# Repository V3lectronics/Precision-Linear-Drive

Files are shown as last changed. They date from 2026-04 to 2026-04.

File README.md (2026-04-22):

# Precision-Linear-Drive

**Technical drawings available, see [DRAWINGS.pdf](DRAWINGS.pdf)**

Highly precise linear drive with a planetary gearbox coupled to a simple gear and clutch mechanism. The rotational motion is transferred to a screw mechanism which outputs linear motion. The motion range is limited by limit switches. The optical encoder allows for precise position feedback.





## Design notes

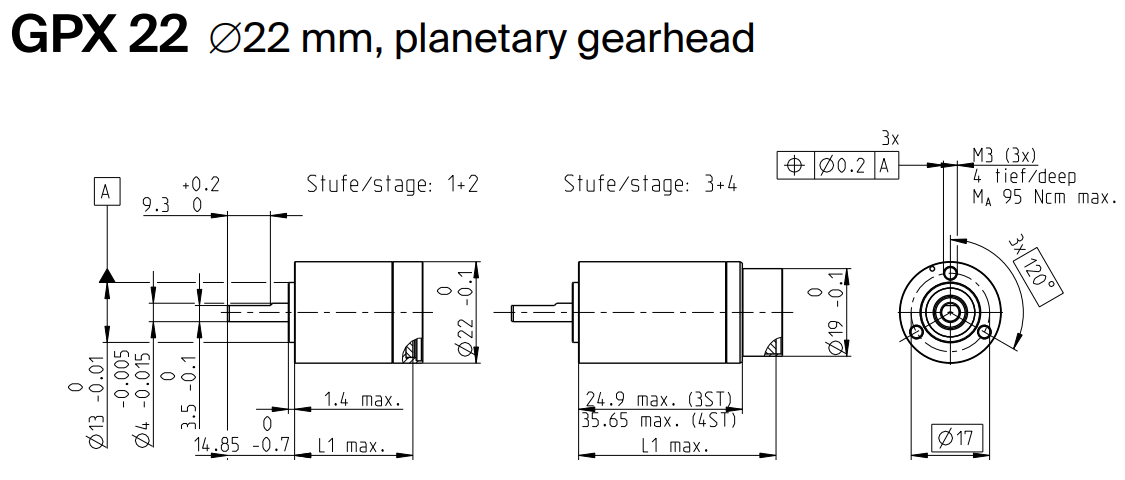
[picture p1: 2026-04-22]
motor-and-planetary-gear-info/Gear (1).PNG

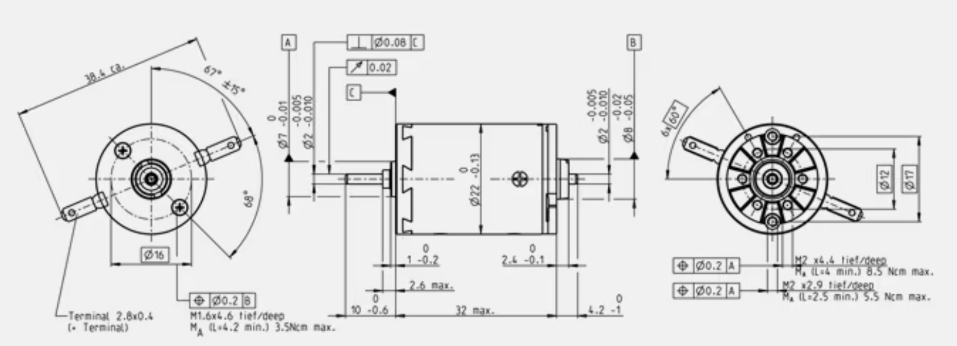
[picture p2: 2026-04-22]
motor-and-planetary-gear-info/Motor (1).PNG

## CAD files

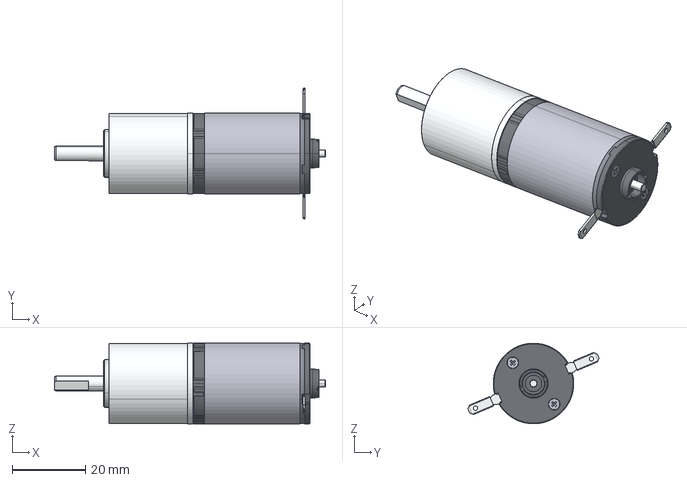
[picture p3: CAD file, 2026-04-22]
parts/motor-and-drive (1).stp
74.0 x 35.8 x 22.0 mm

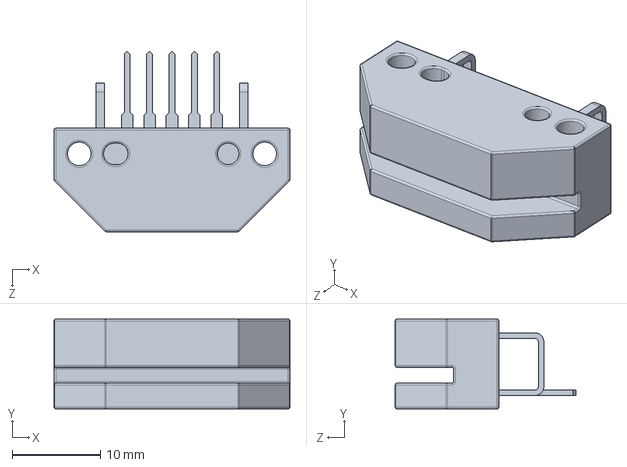
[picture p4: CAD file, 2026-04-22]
parts/HEDS9100 (1).sldprt
26.7 x 10.2 x 20.4 mm

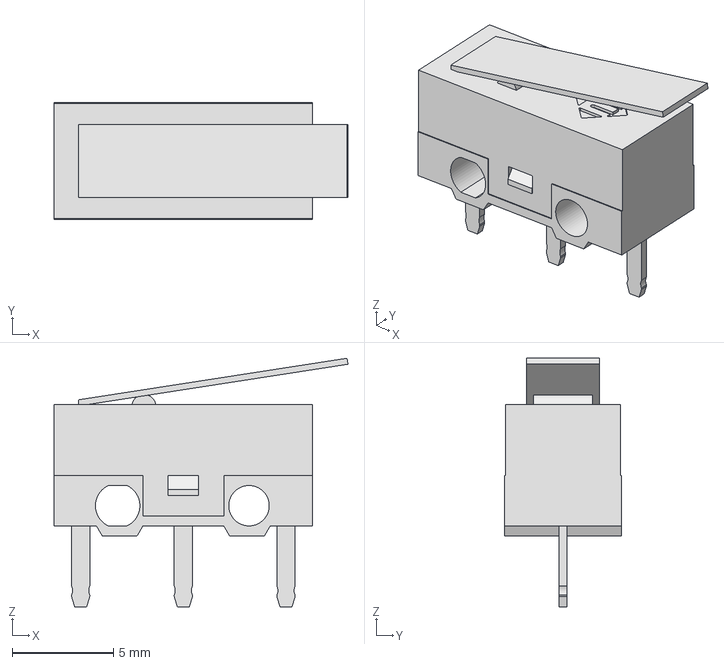
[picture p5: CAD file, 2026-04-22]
parts/SS0750301F040P1A (1).stp
14.5 x 5.80 x 12.3 mm

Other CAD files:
parts/rysunki (1)/tuleja łożyska-1.dwg
parts/rysunki (1)/nakrętka.dwg
parts/rysunki (1)/RYS złożeniowy (1).dwg
parts/rysunki (1)/płyta silnika.dwg
parts/rysunki (1)/słupek.dwg
parts/rysunki (1)/zespół płyty.dwg
parts/rysunki (1)/OldVersions (1)/RYS złożeniowy.0215.dwg
parts/rysunki (1)/OldVersions (1)/płyta silnika.0081.dwg
parts/rysunki (1)/OldVersions (1)/tuleja łożyska-1.0076.dwg
parts/rysunki (1)/OldVersions (1)/nakrętka.0101.dwg
parts/rysunki (1)/OldVersions (1)/zespół płyty.0015.dwg
parts/rysunki (1)/OldVersions (1)/słupek.0063.dwg
Assembly1.iam
parts/619_9 (1).iam
parts/619_9_01 (1).ipt
parts/619_9_02 (1).ipt
parts/619_9_03 (1).ipt
parts/Compress Spring11 (1).ipt
parts/HEDS9100 (1)/HEDS9100 (1)/HEDS9100 (1).ipt
parts/OldVersions (1)/619_9.0009 (1).iam
parts/OldVersions (1)/619_9_01.0001 (1).ipt
parts/OldVersions (1)/619_9_02.0001 (1).ipt
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

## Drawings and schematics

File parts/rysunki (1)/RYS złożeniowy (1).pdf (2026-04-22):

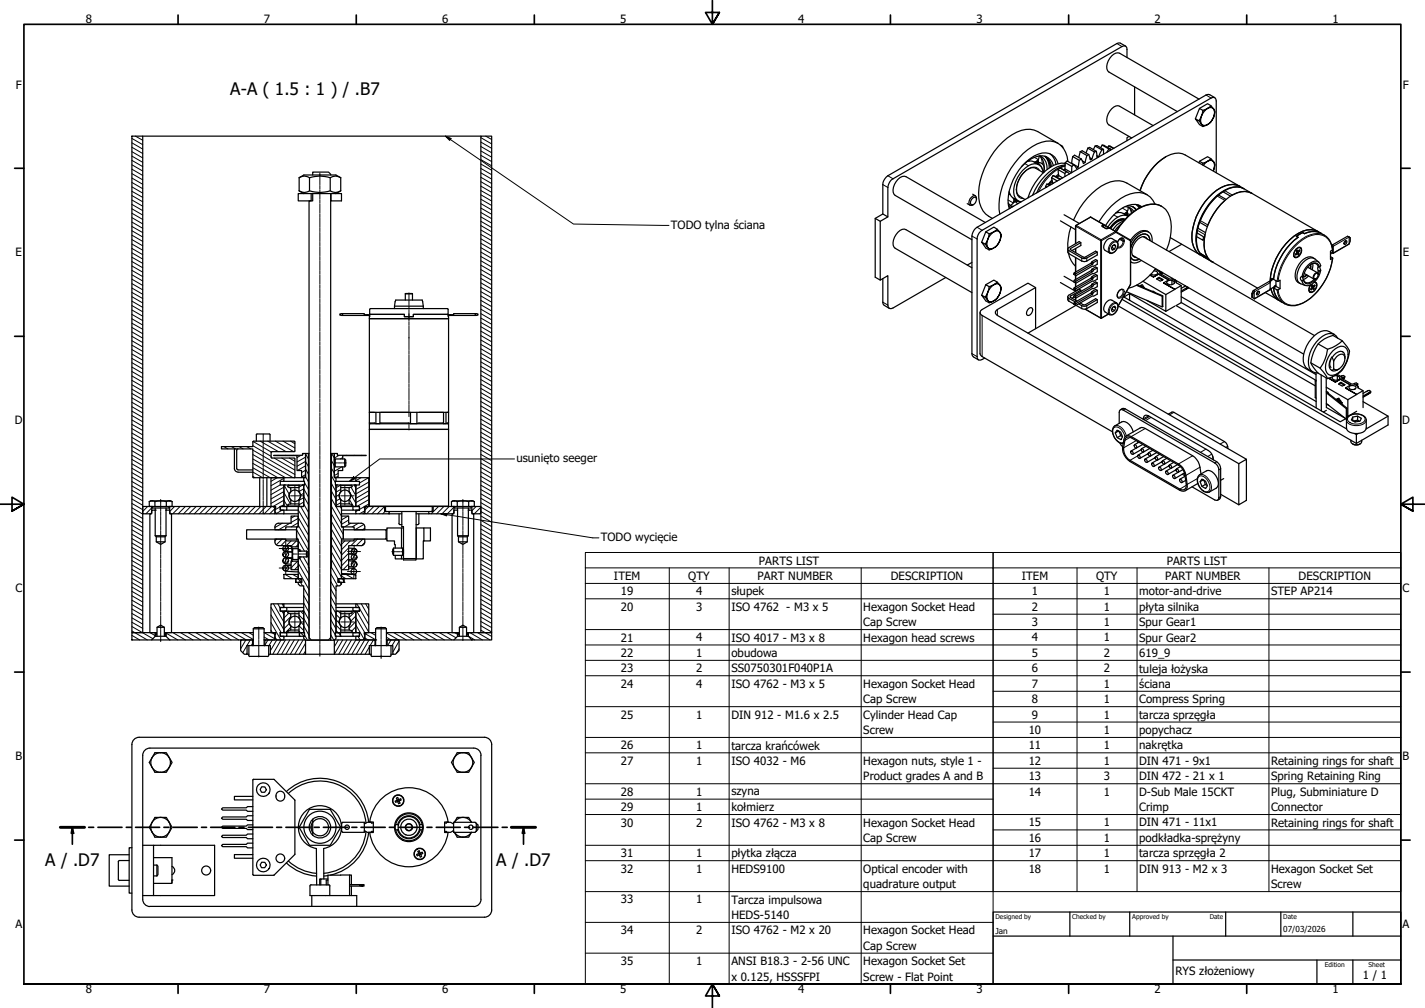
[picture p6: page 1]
Designed by; Checked by; Approved by; Date; usunięto seeger; TODO wycięcie

TODO tylna ściana

PARTS LIST | PARTS LIST

ITEM | QTY | PART NUMBER | DESCRIPTION | ITEM | QTY | PART NUMBER | DESCRIPTION
19 | 4 | słupek | | 1 | 1 | motor-and-drive | STEP AP214
20 | 3 | ISO 4762 - M3 x 5 | Hexagon Socket Head Cap Screw | 2 | 1 | płyta silnika

3 | 1 | Spur Gear1

21 | 4 | ISO 4017 - M3 x 8 | Hexagon head screws | 4 | 1 | Spur Gear2
22 | 1 | obudowa | | 5 | 2 | 619_9
23 | 2 | SS0750301F040P1A | | 6 | 2 | tuleja łożyska
24 | 4 | ISO 4762 - M3 x 5 | Hexagon Socket Head Cap Screw | 7 | 1 | ściana

8 | 1 | Compress Spring

25 | 1 | DIN 912 - M1.6 x 2.5 | Cylinder Head Cap Screw | 9 | 1 | tarcza sprzęgła

10 | 1 | popychacz

26 | 1 | tarcza krańcówek | | 11 | 1 | nakrętka
27 | 1 | ISO 4032 - M6 | Hexagon nuts, style 1 -Product grades A and B | 12 | 1 | DIN 471 - 9x1 | Retaining rings for shaft

13 | 3 | DIN 472 - 21 x 1 | Spring Retaining Ring

28 | 1 | szyna | | 14 | 1 | D-Sub Male 15CKT Crimp | Plug, Subminiature D Connector
29 | 1 | kołmierz
30 | 2 | ISO 4762 - M3 x 8 | Hexagon Socket Head Cap Screw | 15 | 1 | DIN 471 - 11x1 | Retaining rings for shaft

16 | 1 | podkładka-sprężyny

31 | 1 | płytka złącza | | 17 | 1 | tarcza sprzęgła 2
32 | 1 | HEDS9100 | Optical encoder with quadrature output | 18 | 1 | DIN 913 - M2 x 3 | Hexagon Socket Set Screw

33 | 1 | Tarcza impulsowa HEDS-5140

34 | 2 | ISO 4762 - M2 x 20 | Hexagon Socket Head Cap Screw

35 | 1 | ANSI B18.3 - 2-56 UNC x 0.125, HSSSFPI | Hexagon Socket Set Screw - Flat Point

RYS złożeniowy | Edition | Sheet 1 / 1

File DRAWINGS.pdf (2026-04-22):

A-A

B-B

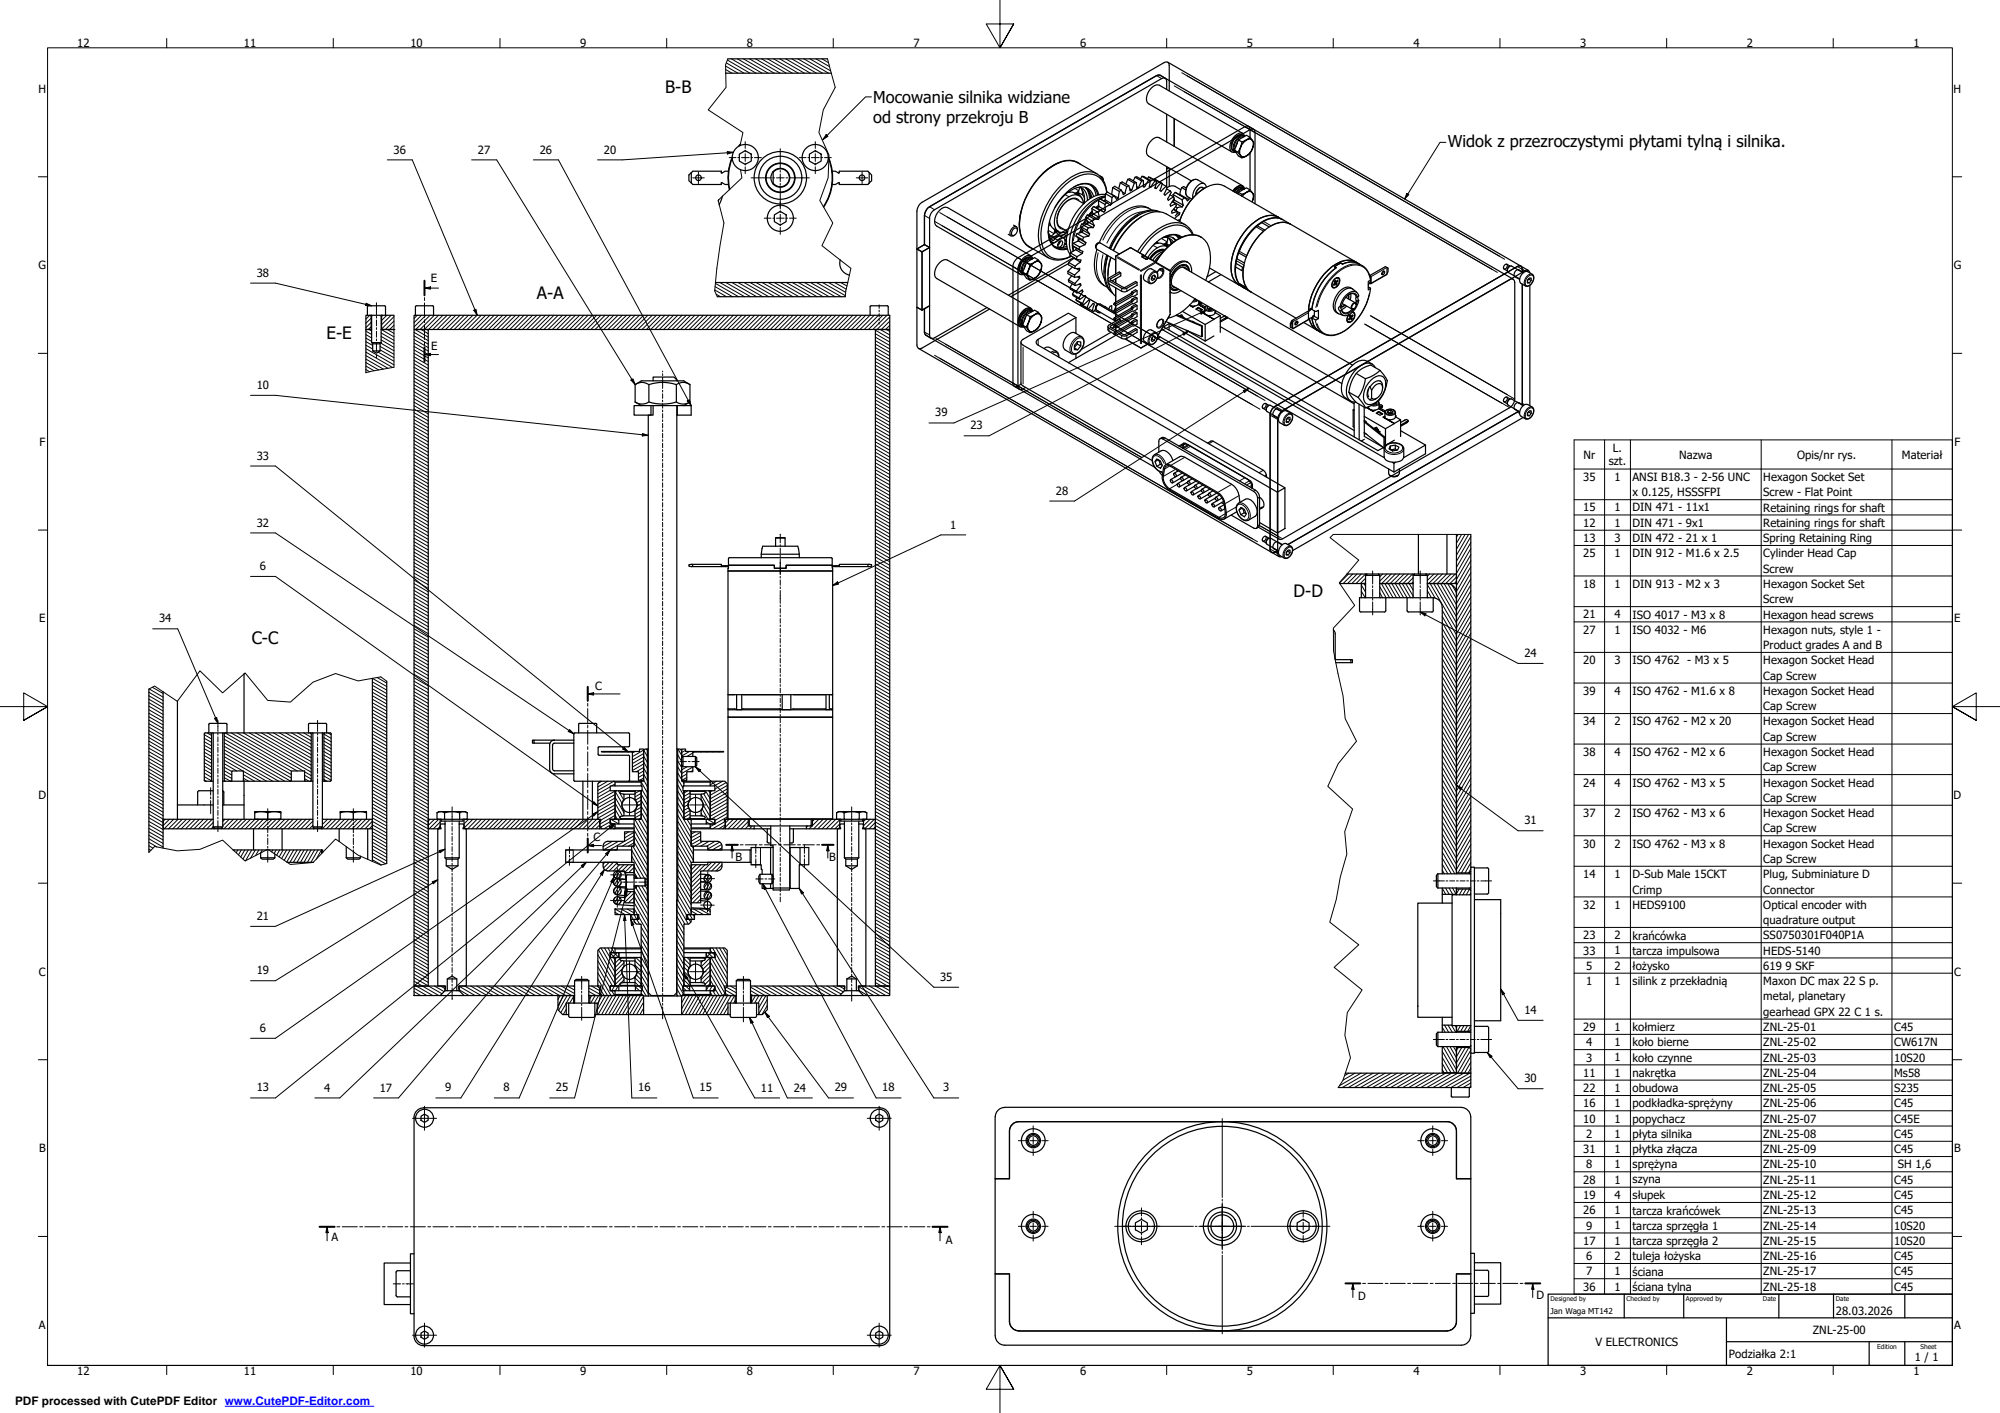
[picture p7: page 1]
Nazwa; Opis/nr rys.; Materiał; L. szt.; ściana tylna; ZNL-25-18; ZNL-25-00; Podziałka 2:1; V ELECTRONICS; Jan Waga MT142; Designed by; Checked by; Approved by; Date; Edition; Sheet

Mocowanie silnika widziane
od strony przekroju B

Widok z przezroczystymi płytami tylną i silnika.

35 | 1 | ANSI B18.3 - 2-56 UNC x 0.125, HSSSFPI | Hexagon Socket Set Screw - Flat Point

15 | 1 | DIN 471 - 11x1 | Retaining rings for shaft
12 13 | 1 3 | DIN 471 - 9x1 DIN 472 - 21 x 1 | Retaining rings for shaft Spring Retaining Ring

25 | 1 | DIN 912 - M1.6 x 2.5 | Cylinder Head Cap Screw

18 | 1 | DIN 913 - M2 x 3 | Hexagon Socket Set Screw

21 | 4 | ISO 4017 - M3 x 8 | Hexagon head screws
27 | 1 | ISO 4032 - M6 | Hexagon nuts, style 1 -Product grades A and B

20 | 3 | ISO 4762 - M3 x 5 | Hexagon Socket Head Cap Screw

39 | 4 | ISO 4762 - M1.6 x 8 | Hexagon Socket Head Cap Screw

34 | 2 | ISO 4762 - M2 x 20 | Hexagon Socket Head Cap Screw

38 | 4 | ISO 4762 - M2 x 6 | Hexagon Socket Head Cap Screw

24 | 4 | ISO 4762 - M3 x 5 | Hexagon Socket Head Cap Screw

37 | 2 | ISO 4762 - M3 x 6 | Hexagon Socket Head Cap Screw

30 | 2 | ISO 4762 - M3 x 8 | Hexagon Socket Head Cap Screw

14 | 1 | D-Sub Male 15CKT Crimp | Plug, Subminiature D Connector

32 | 1 | HEDS9100 | Optical encoder with quadrature output

23 | 2 | krańcówka | SS0750301F040P1A
33 | 1 | tarcza impulsowa | HEDS-5140
5 | 2 | łożysko | 619 9 SKF
1 | 1 | silink z przekładnią | Maxon DC max 22 S p. metal, planetary gearhead GPX 22 C 1 s.

29 | 1 | kołmierz | ZNL-25-01 | C45
4 | 1 | koło bierne | ZNL-25-02 | CW617N
3 | 1 | koło czynne | ZNL-25-03 | 10S20
11 | 1 | nakrętka | ZNL-25-04 | Ms58
22 | 1 | obudowa | ZNL-25-05 | S235
16 | 1 | podkładka-sprężyny | ZNL-25-06 | C45
10 | 1 | popychacz | ZNL-25-07 | C45E
2 | 1 | płyta silnika | ZNL-25-08 | C45
31 | 1 | płytka złącza | ZNL-25-09 | C45
8 | 1 | sprężyna | ZNL-25-10 | SH 1,6
28 | 1 | szyna | ZNL-25-11 | C45
19 | 4 | słupek | ZNL-25-12 | C45
26 | 1 | tarcza krańcówek | ZNL-25-13 | C45
9 | 1 | tarcza sprzęgła 1 | ZNL-25-14 | 10S20
17 | 1 | tarcza sprzęgła 2 | ZNL-25-15 | 10S20
6 | 2 | tuleja łożyska | ZNL-25-16 | C45
7 | 1 | ściana | ZNL-25-17 | C45

PDF processed with CutePDF Editor www.CutePDF-Editor.com

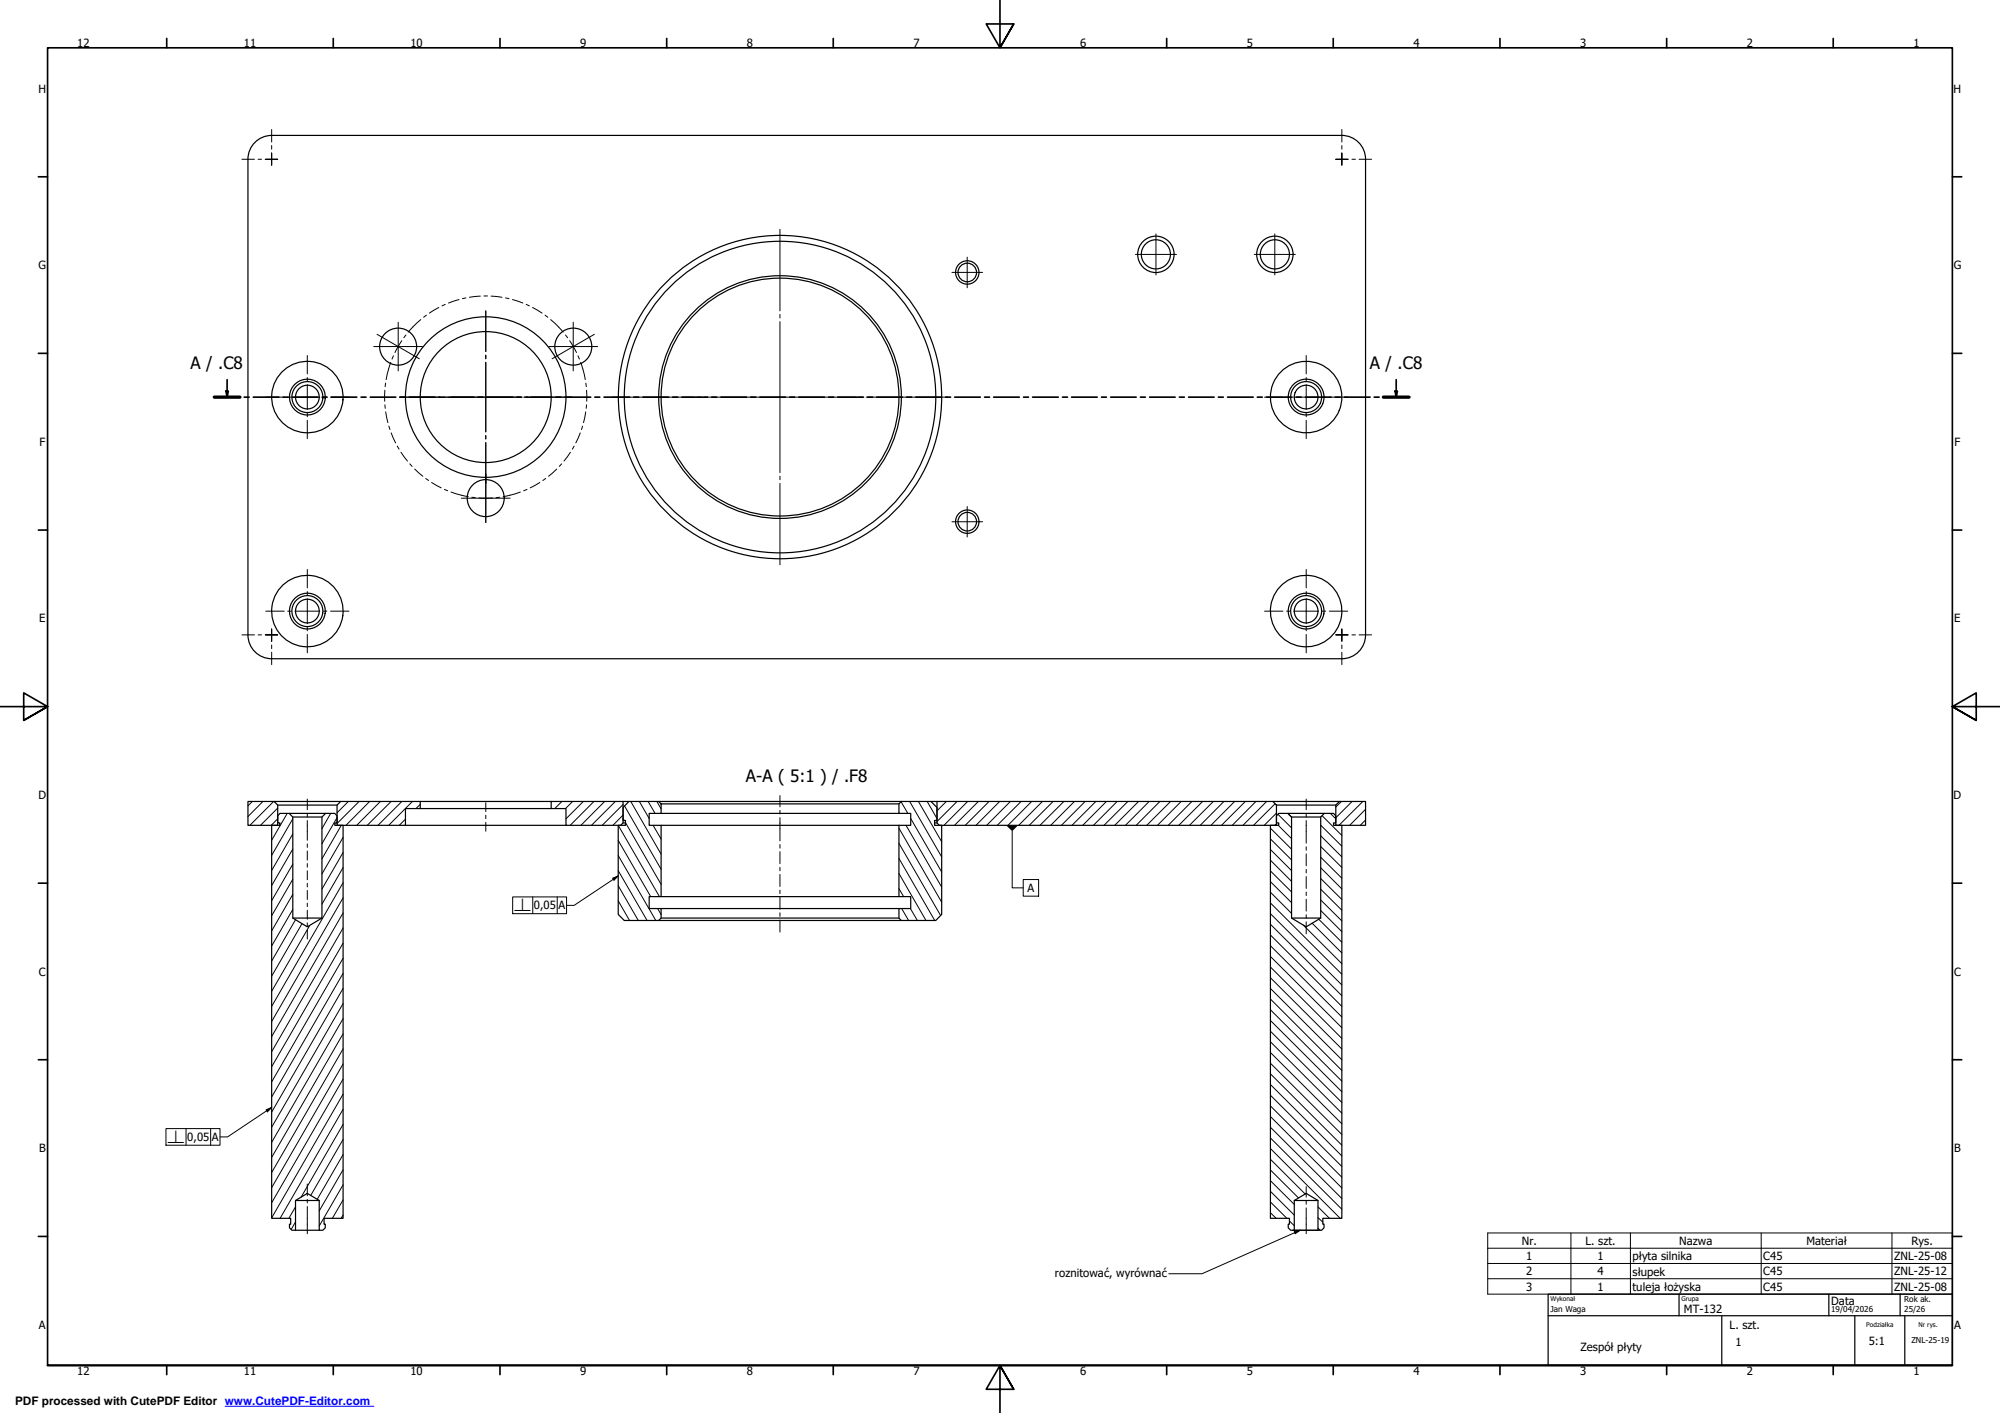
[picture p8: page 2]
L. szt.; Nazwa; Materiał; Rys.; tuleja łożyska; ZNL-25-08; Zespół płyty; Jan Waga; Wykonał; Grupa; Data; Podziałka; Nr rys. . szt.; Rok ak.; roznitować, wyrównać; ZNL-25-19

1 | 1 | płyta silnika | C45 | ZNL-25-08
2 | 4 | słupek | C45 | ZNL-25-12

( | )

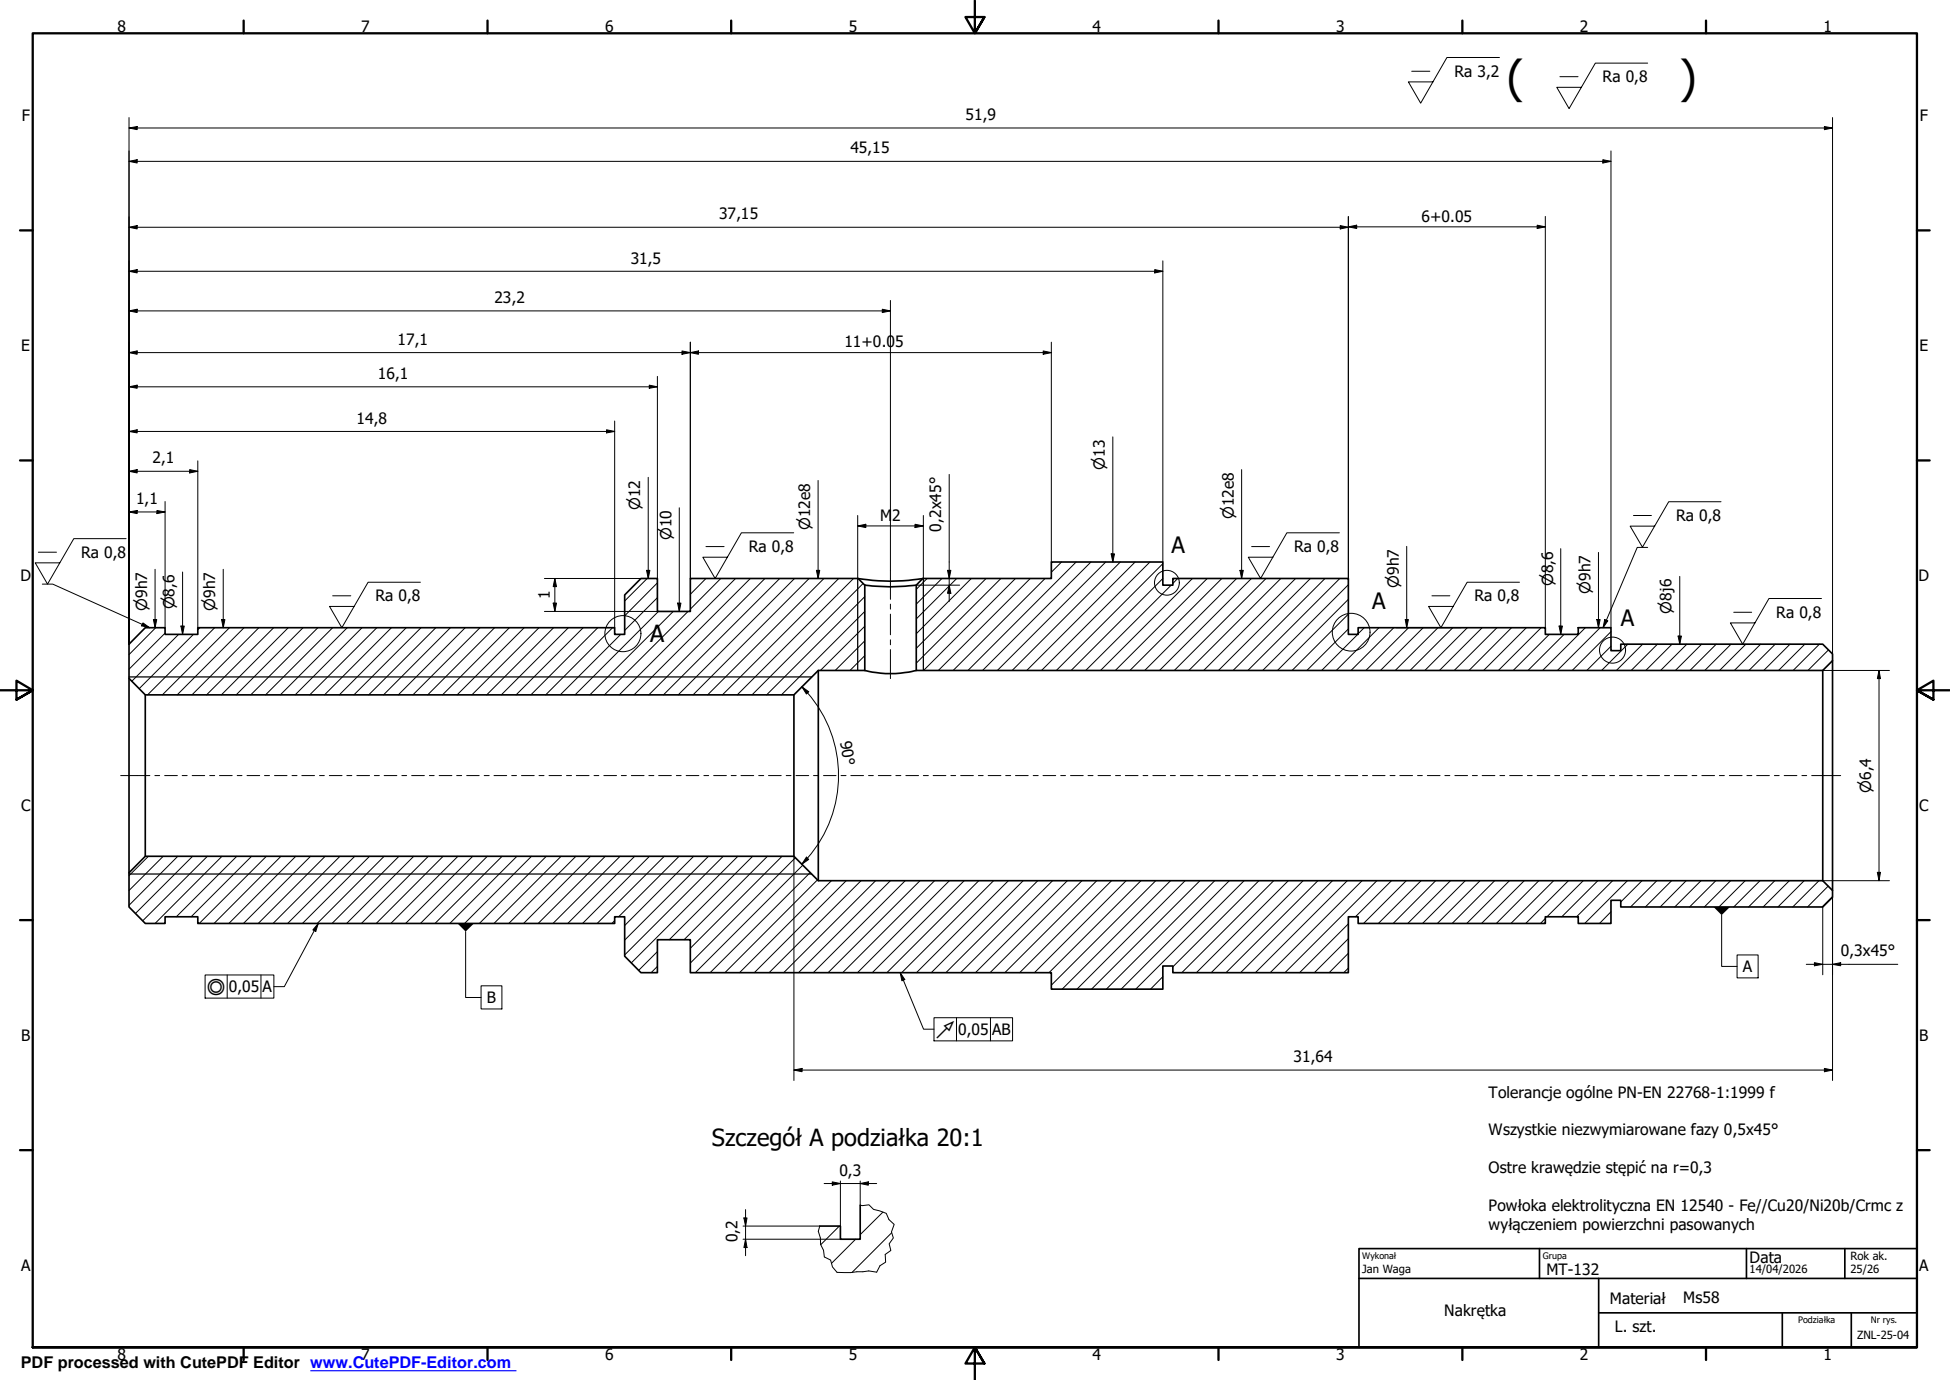
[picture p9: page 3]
Szczegół A podziałka 20:1; Materiał; Jan Waga; Wykonał; Grupa; Data; Podziałka; Nr rys.; L. szt.; Rok ak.; Nakrętka

Tolerancje ogólne PN-EN 22768-1:1999 f

Wszystkie niezwymiarowane fazy 0,5x45°

Ostre krawędzie stępić na r=0,3

Powłoka elektrolityczna EN 12540 - Fe//Cu20/Ni20b/Crmc z
wyłączeniem powierzchni pasowanych

A-A

n5

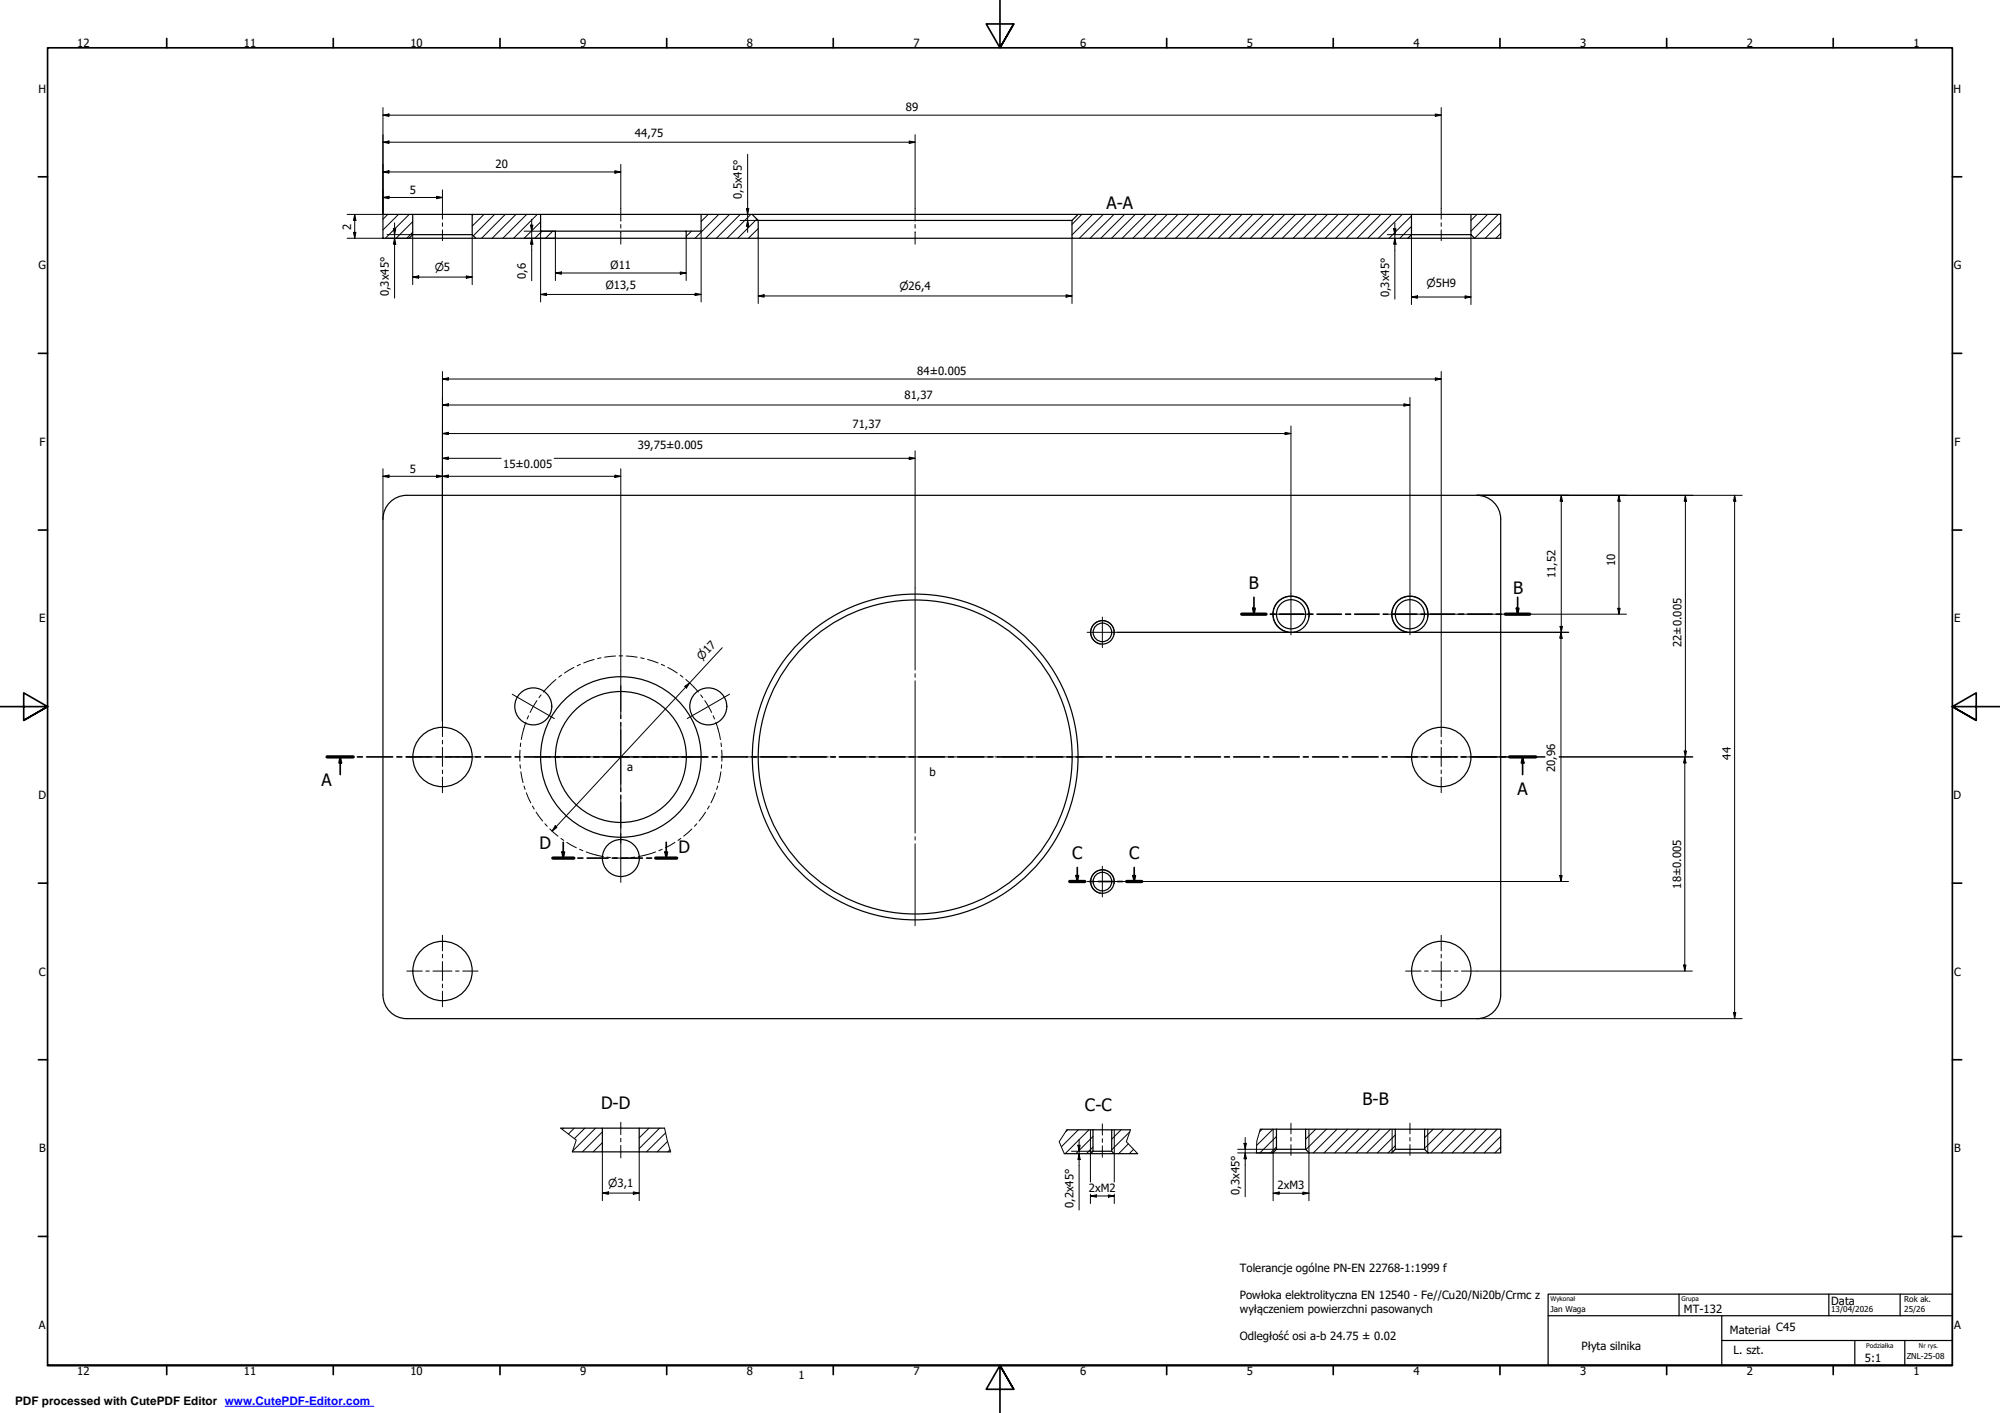
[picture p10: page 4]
Płyta silnika; Jan Waga; Wykonał; Grupa; Data; Rok ak.; Odległość osi a-b 24.75 ± 0.02; ZNL-25-08

Tolerancje ogólne PN-EN 22768-1:1999 f

Powłoka elektrolityczna EN 12540 - Fe//Cu20/Ni20b/Crmc z
wyłączeniem powierzchni pasowanych

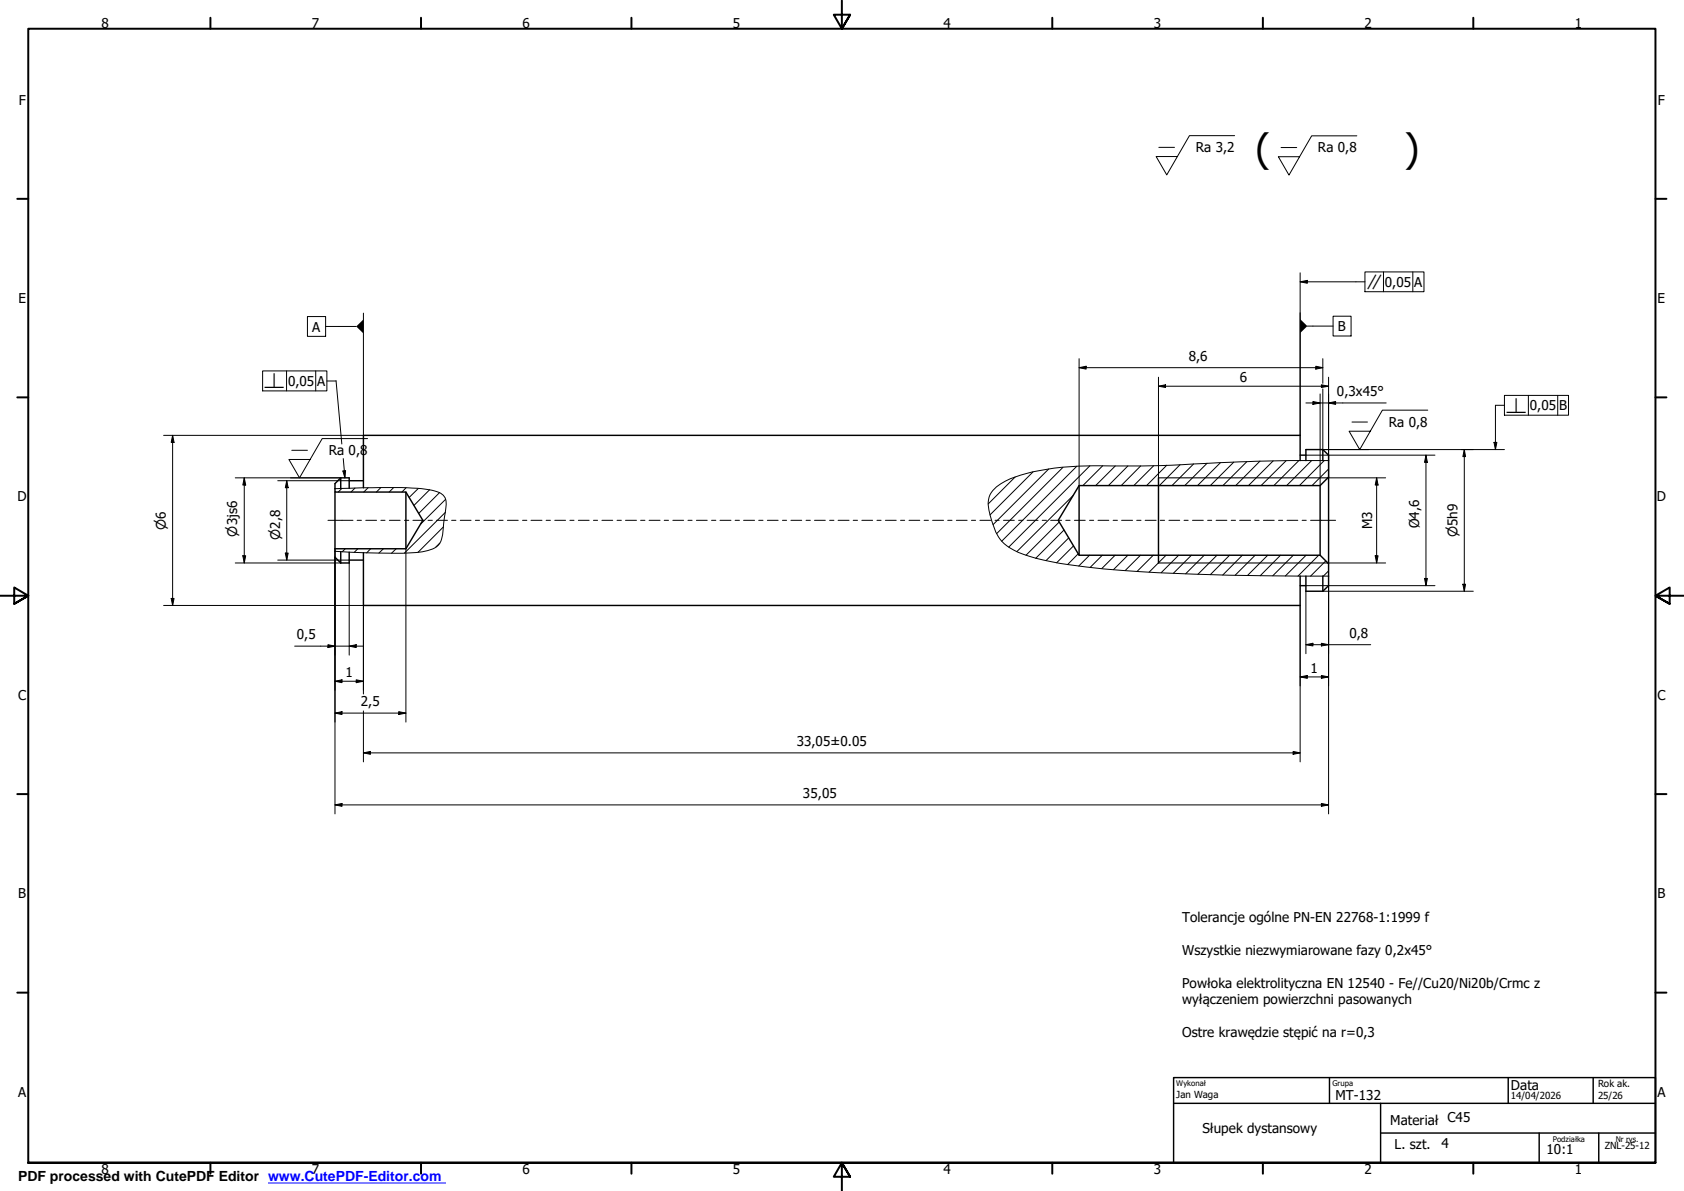
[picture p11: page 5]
Jan Waga; Wykonał; Grupa; Data; Rok ak.; Słupek dystansowy; ZNL-25-12

Tolerancje ogólne PN-EN 22768-1:1999 f

Wszystkie niezwymiarowane fazy 0,2x45°

Powłoka elektrolityczna EN 12540 - Fe//Cu20/Ni20b/Crmc z
wyłączeniem powierzchni pasowanych

Ostre krawędzie stępić na r=0,3

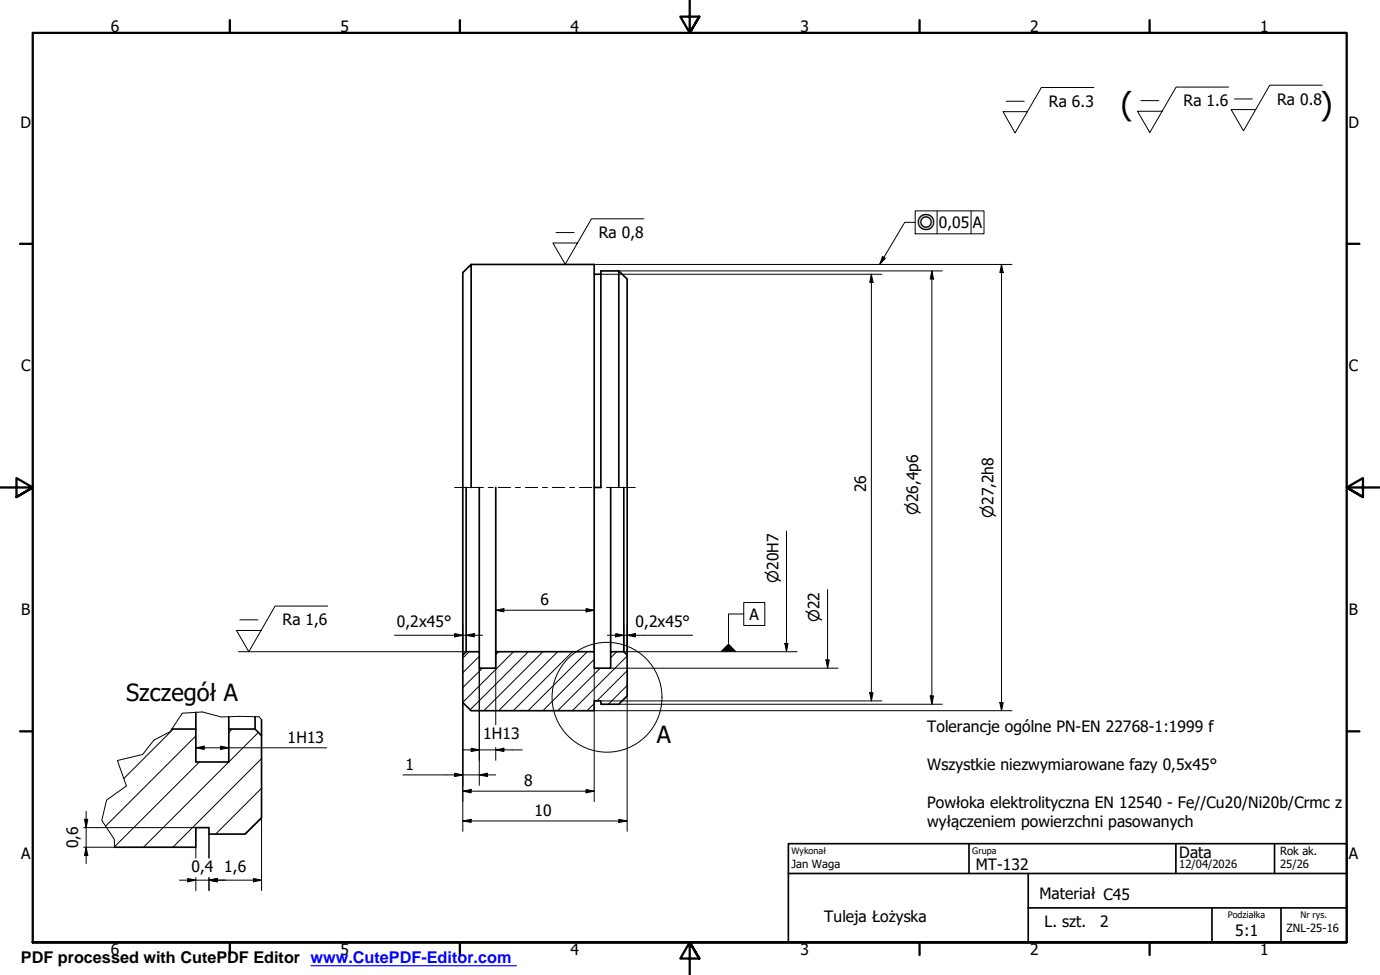
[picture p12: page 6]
Szczegół A; Materiał; Tuleja Łożyska; Jan Waga; Wykonał; Grupa; Data; Rok ak. 25/26

Tolerancje ogólne PN-EN 22768-1:1999 f

Wszystkie niezwymiarowane fazy 0,5x45°

Powłoka elektrolityczna EN 12540 - Fe//Cu20/Ni20b/Crmc z
wyłączeniem powierzchni pasowanych

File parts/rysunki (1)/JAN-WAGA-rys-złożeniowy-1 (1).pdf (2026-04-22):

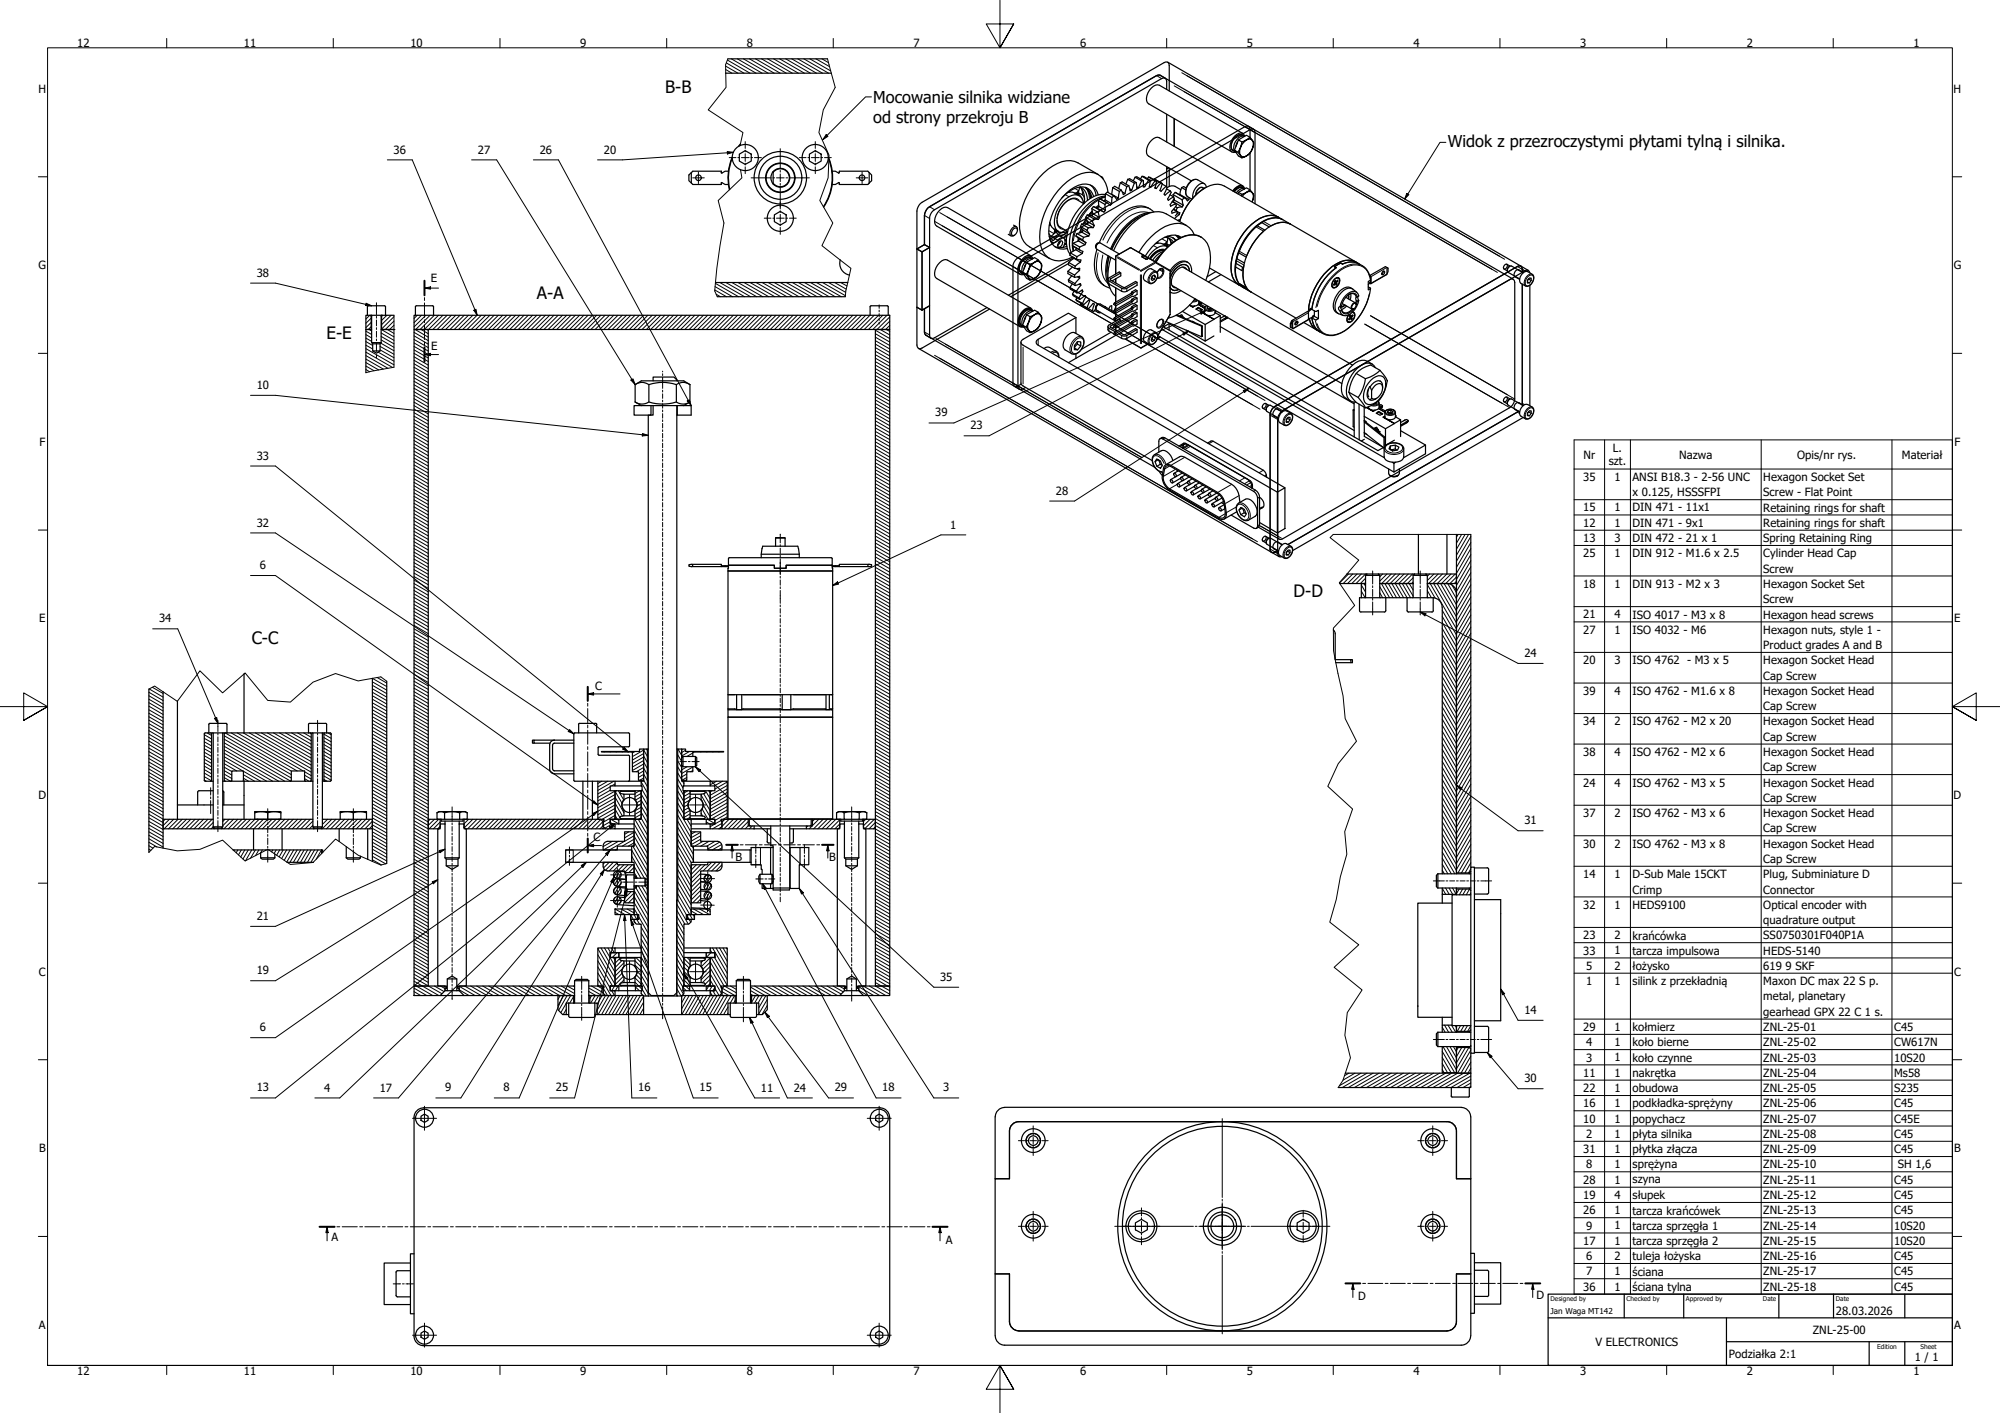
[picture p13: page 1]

3 5 | 1 | A N S I B 1 8 . 3 -2 -5 6 U N C x 0 . 1 2 5 , H S S S F P I | H e x a g o n S o c k e t S e t S c r e w -Fla t P o i n t

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

2 5 | 1 | D I N 9 1 2 -M 1 . 6 x 2 . 5 | C yli n d e r H e a d C a p S c r e w

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

2 3 | 2 | k r a ń c ó w k a | S S 0 7 5 0 3 0 1 F 0 4 0 P 1 A
3 3 | 1 | t a r c z a i m p uls o w a | H E D S -5 1 4 0
5 | 2 | ł o ż y s k o | 6 1 9 9 S K F
1 | 1 | s ili n k z p r z e kł a d n i ą | M a x o n D C m a x 2 2 S p . m e t al, pla n e t a r y g e a r h e a d G P X 2 2 C 1 s .

2 9 | 1 | k o ł m i e r z | Z N L -2 5 -0 1 | C 4 5
4 | 1 | k o ł o b i e r n e | Z N L -2 5 -0 2 | C W 6 1 7 N
3 | 1 | k o ł o c z y n n e | Z N L -2 5 -0 3 | 1 0 S 2 0
1 1 | 1 | n a k r ę t k a | Z N L -2 5 -0 4 | M s 5 8
2 2 | 1 | o b u d o w a | Z N L -2 5 -0 5 | S 2 3 5
1 6 | 1 | kł p o d a d k a -s p r ę ż y n y | Z N L -2 5 -0 6 | C 4 5
1 0 | 1 | p o p y c h a c z | Z N L -2 5 -0 7 | C 4 5 E
2 | 1 | p ł y t a s iln i k a | Z N L -2 5 -0 8 | C 4 5
3 1 | 1 | p ł y t k a z ł ą c z a | Z N L -2 5 -0 9 | C 4 5
8 | 1 | s p r ę ż y n a | Z N L -2 5 -1 0 | S H 1 , 6
2 8 | 1 | s z y n a | Z N L -2 5 -1 1 | C 4 5
1 9 | 4 | s ł u p e k | Z N L -2 5 -1 2 | C 4 5
2 6 | 1 | t a r c z a k r a ń c ó w e k | Z N L -2 5 -1 3 | C 4 5
9 | 1 | t a r c z a s p r z ę g ł a 1 | Z N L -2 5 -1 4 | 1 0 S 2 0
1 7 | 1 | t a r c z a s p r z ę g ł a 2 | Z N L -2 5 -1 5 | 1 0 S 2 0
6 | 2 | t ulej a ł o ż y s k a | Z N L -2 5 -1 6 | C 4 5
7 | 1 | ś c i a n a | Z N L -2 5 -1 7 | C 4 5
3 6 | 1 | ś c i a n a t yln a | Z N L -2 5 -1 8 | C 4 5

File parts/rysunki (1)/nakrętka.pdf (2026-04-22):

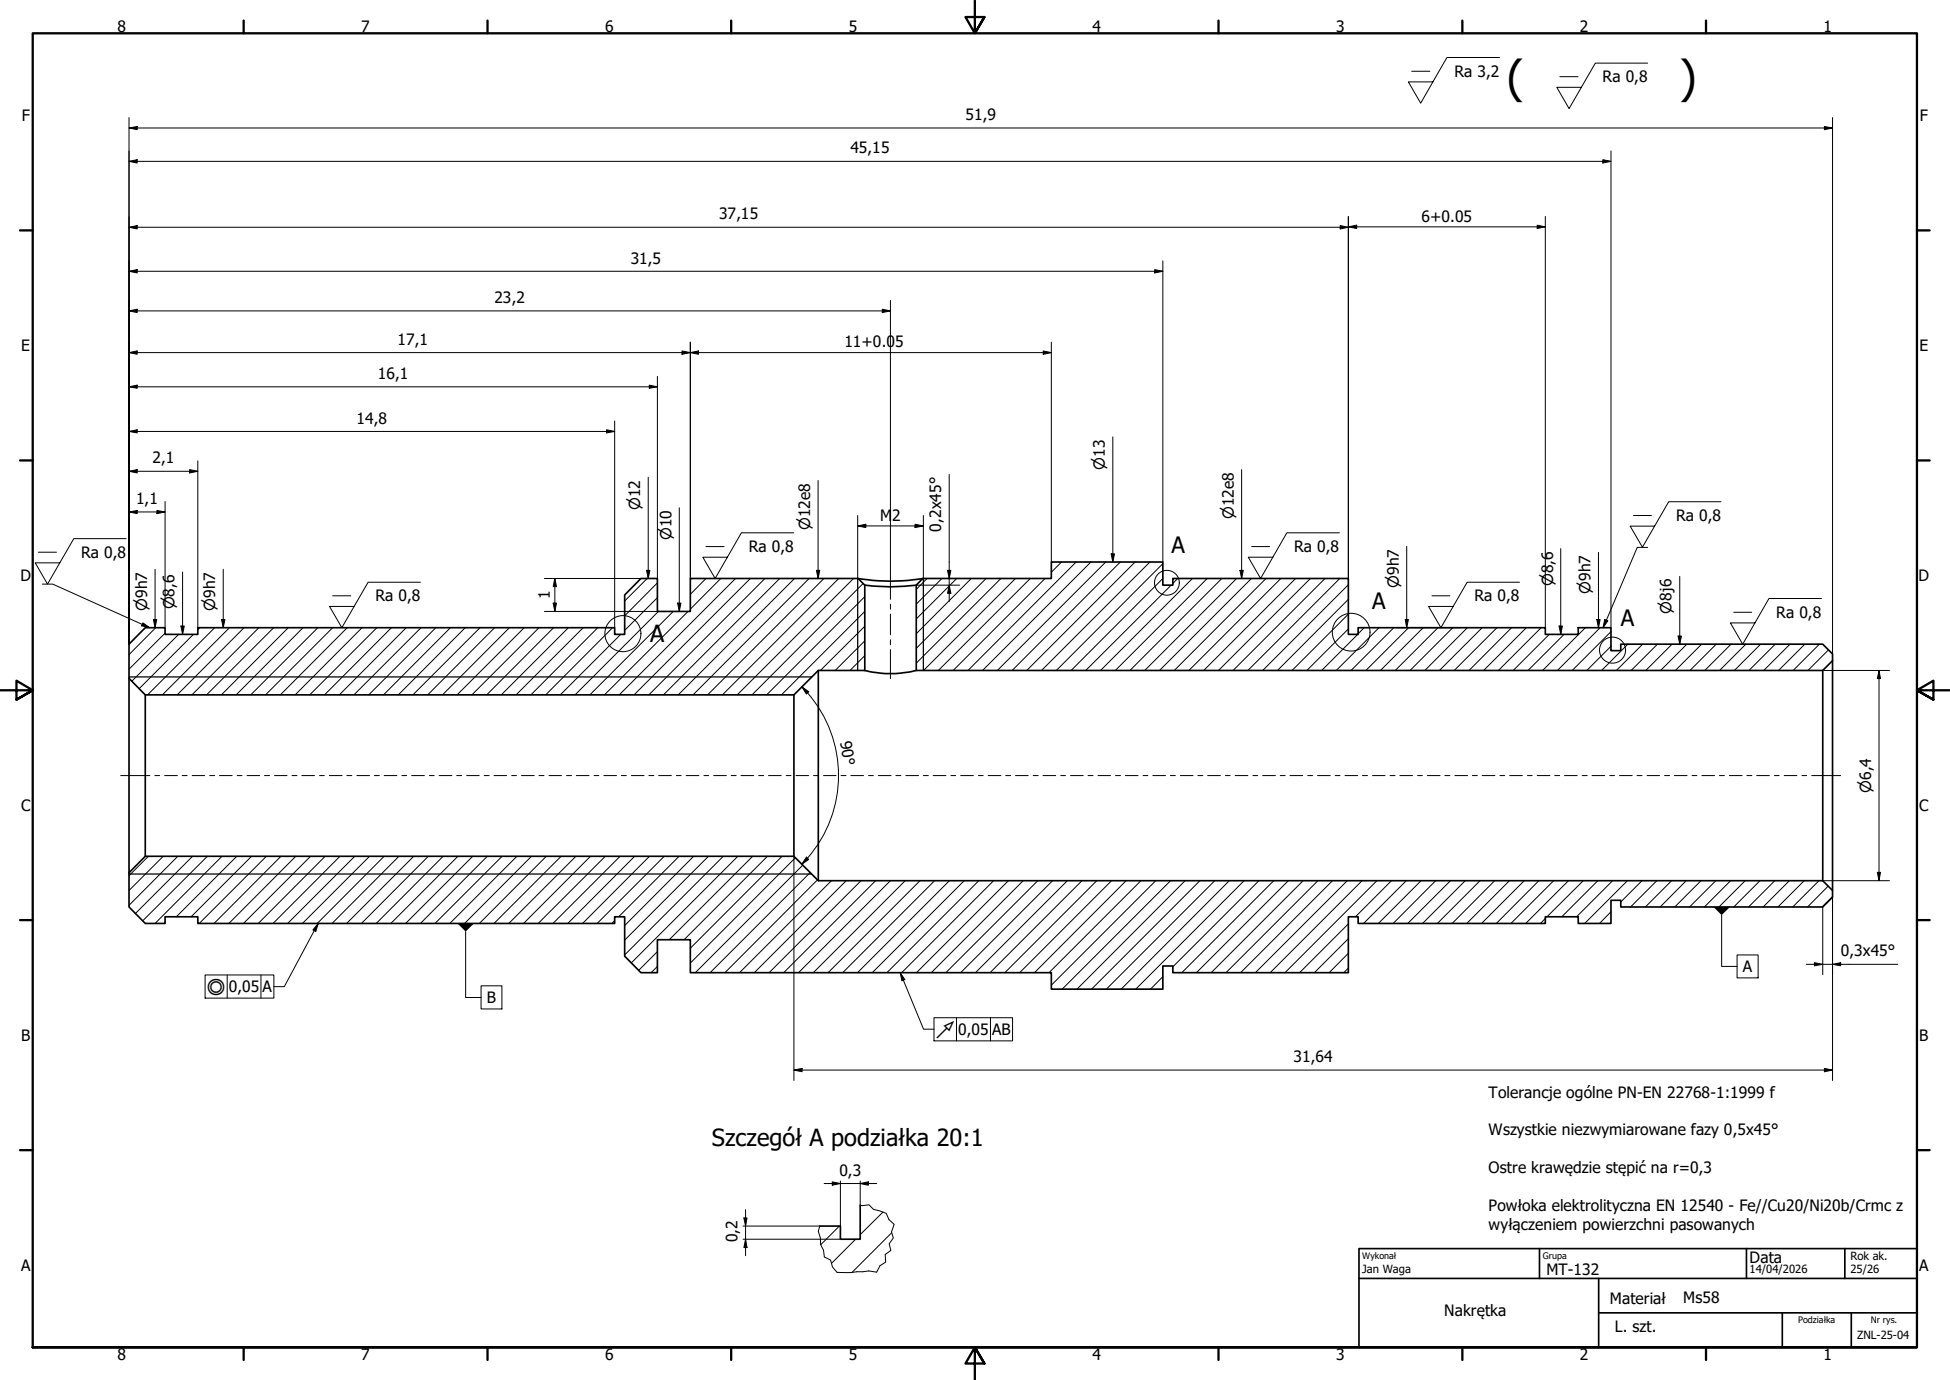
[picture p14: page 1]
Szczegół A podziałka 20:1

Tolerancje ogólne PN-EN 22768-1:1999 f

Wszystkie niezwymiarowane fazy 0,5x45°

Ostre krawędzie stępić na r=0,3

Powłoka elektrolityczna EN 12540 - Fe//Cu20/Ni20b/Crmc z
wyłączeniem powierzchni pasowanych

Wykonał Jan Waga | Grupa MT-132 | Data 14/04/2026 | Rok ak. 25/26

Nakrętka | Ms58 Materiał

L. szt. | Podziałka | Nr rys. ZNL-25-04

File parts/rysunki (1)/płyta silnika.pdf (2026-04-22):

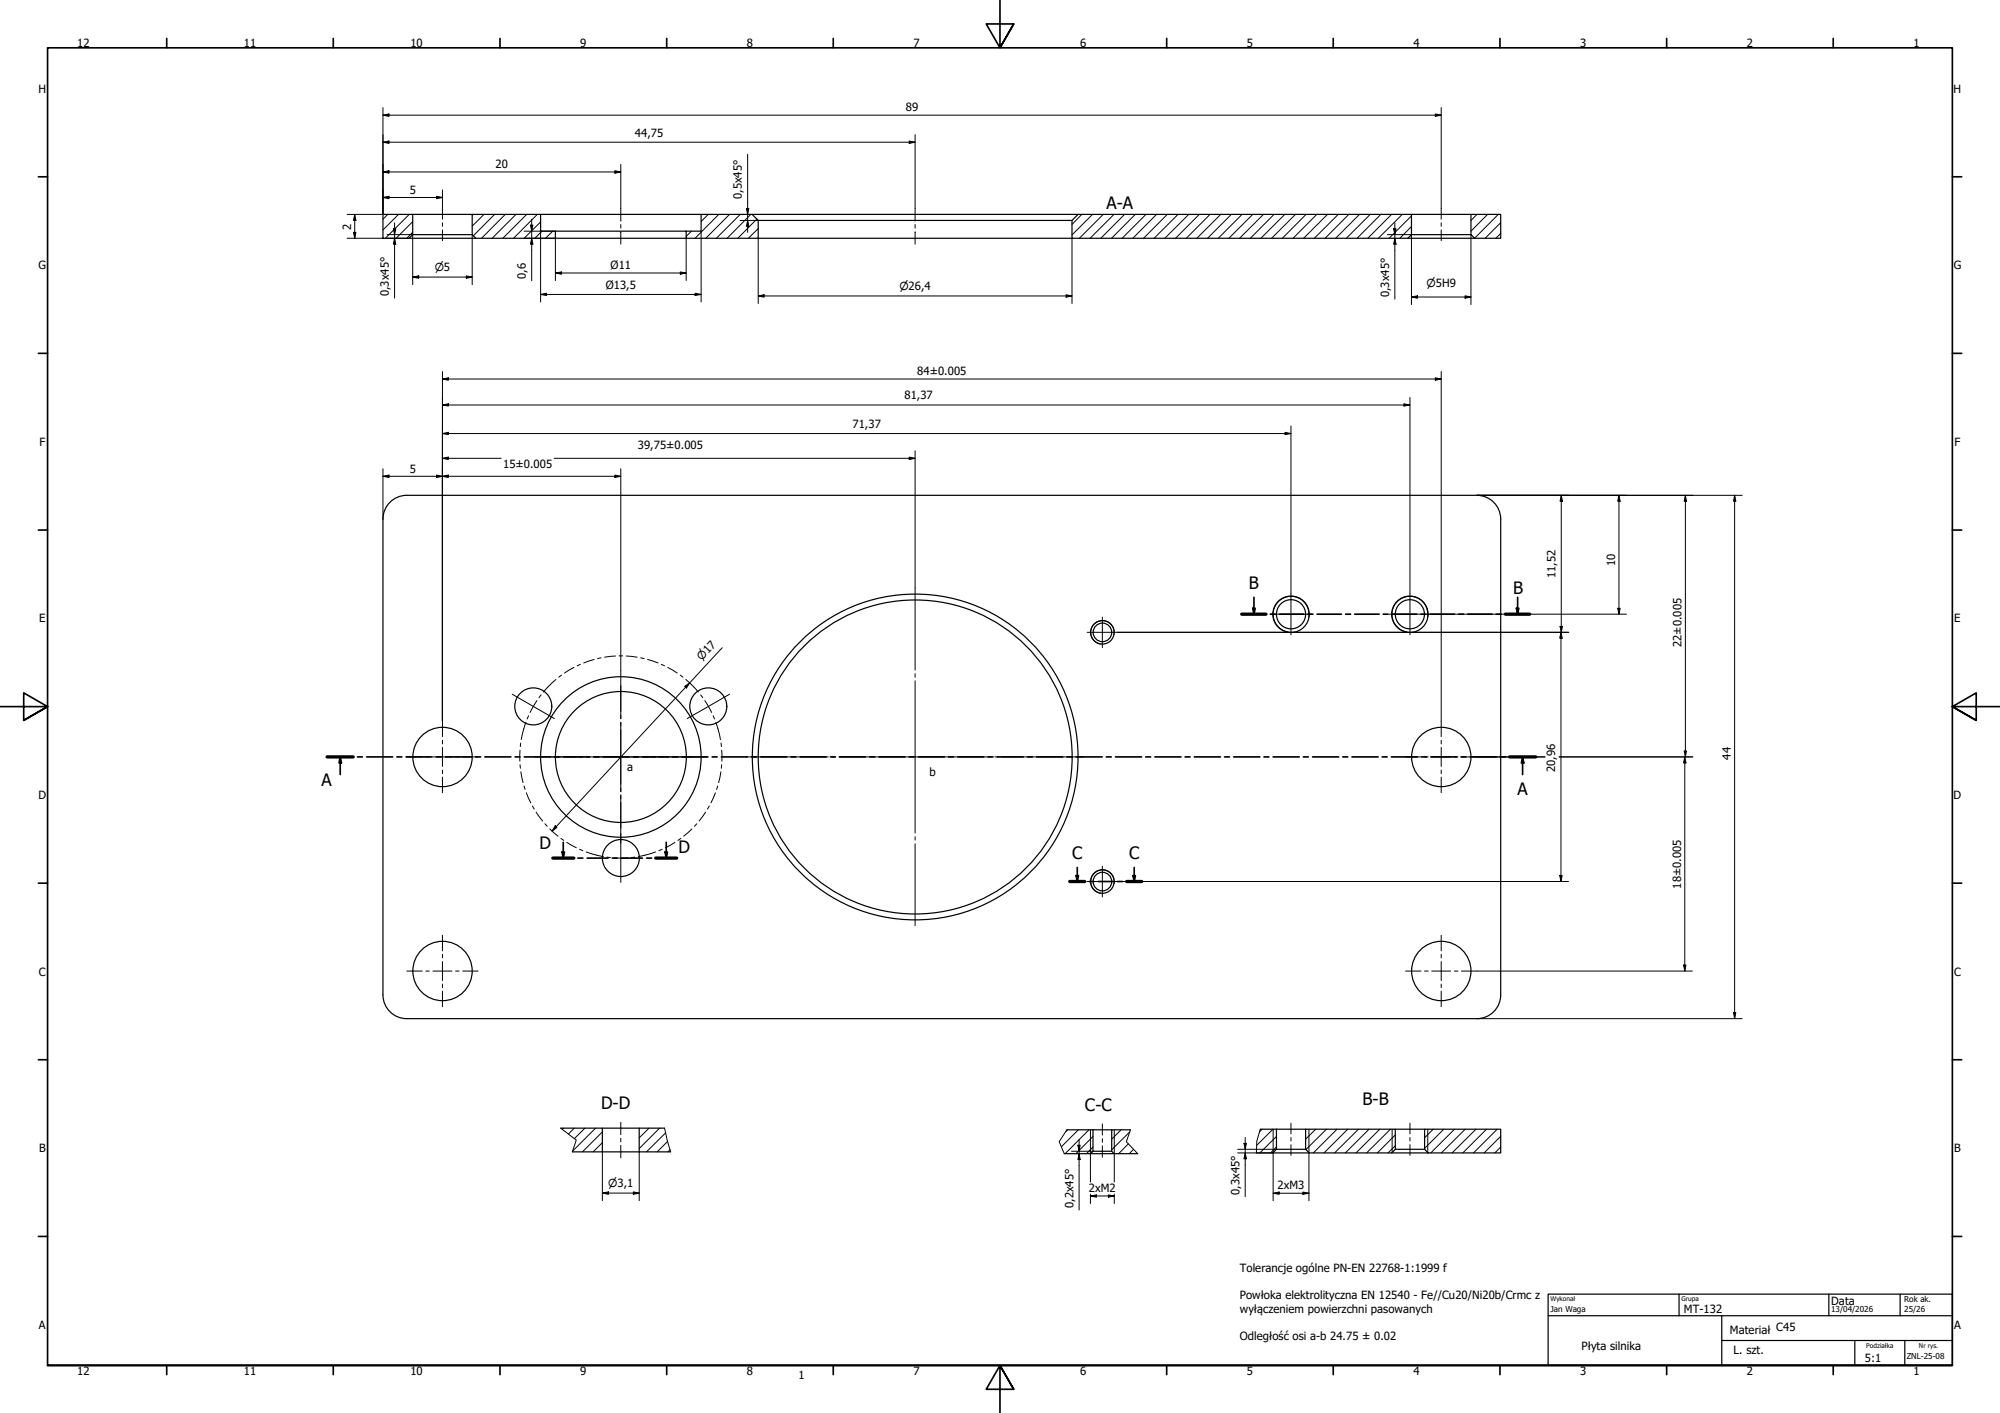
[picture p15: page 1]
Odległość osi a-b 24.75 ± 0.02

Tolerancje ogólne PN-EN 22768-1:1999 f

Powłoka elektrolityczna EN 12540 - Fe//Cu20/Ni20b/Crmc z
wyłączeniem powierzchni pasowanych

Wykonał Jan Waga | Grupa MT-132 | Data 13/04/2026 | Rok ak. 25/26

Płyta silnika | C45 Materiał

L. szt. | Podziałka 5:1 | Nr rys. ZNL-25-08

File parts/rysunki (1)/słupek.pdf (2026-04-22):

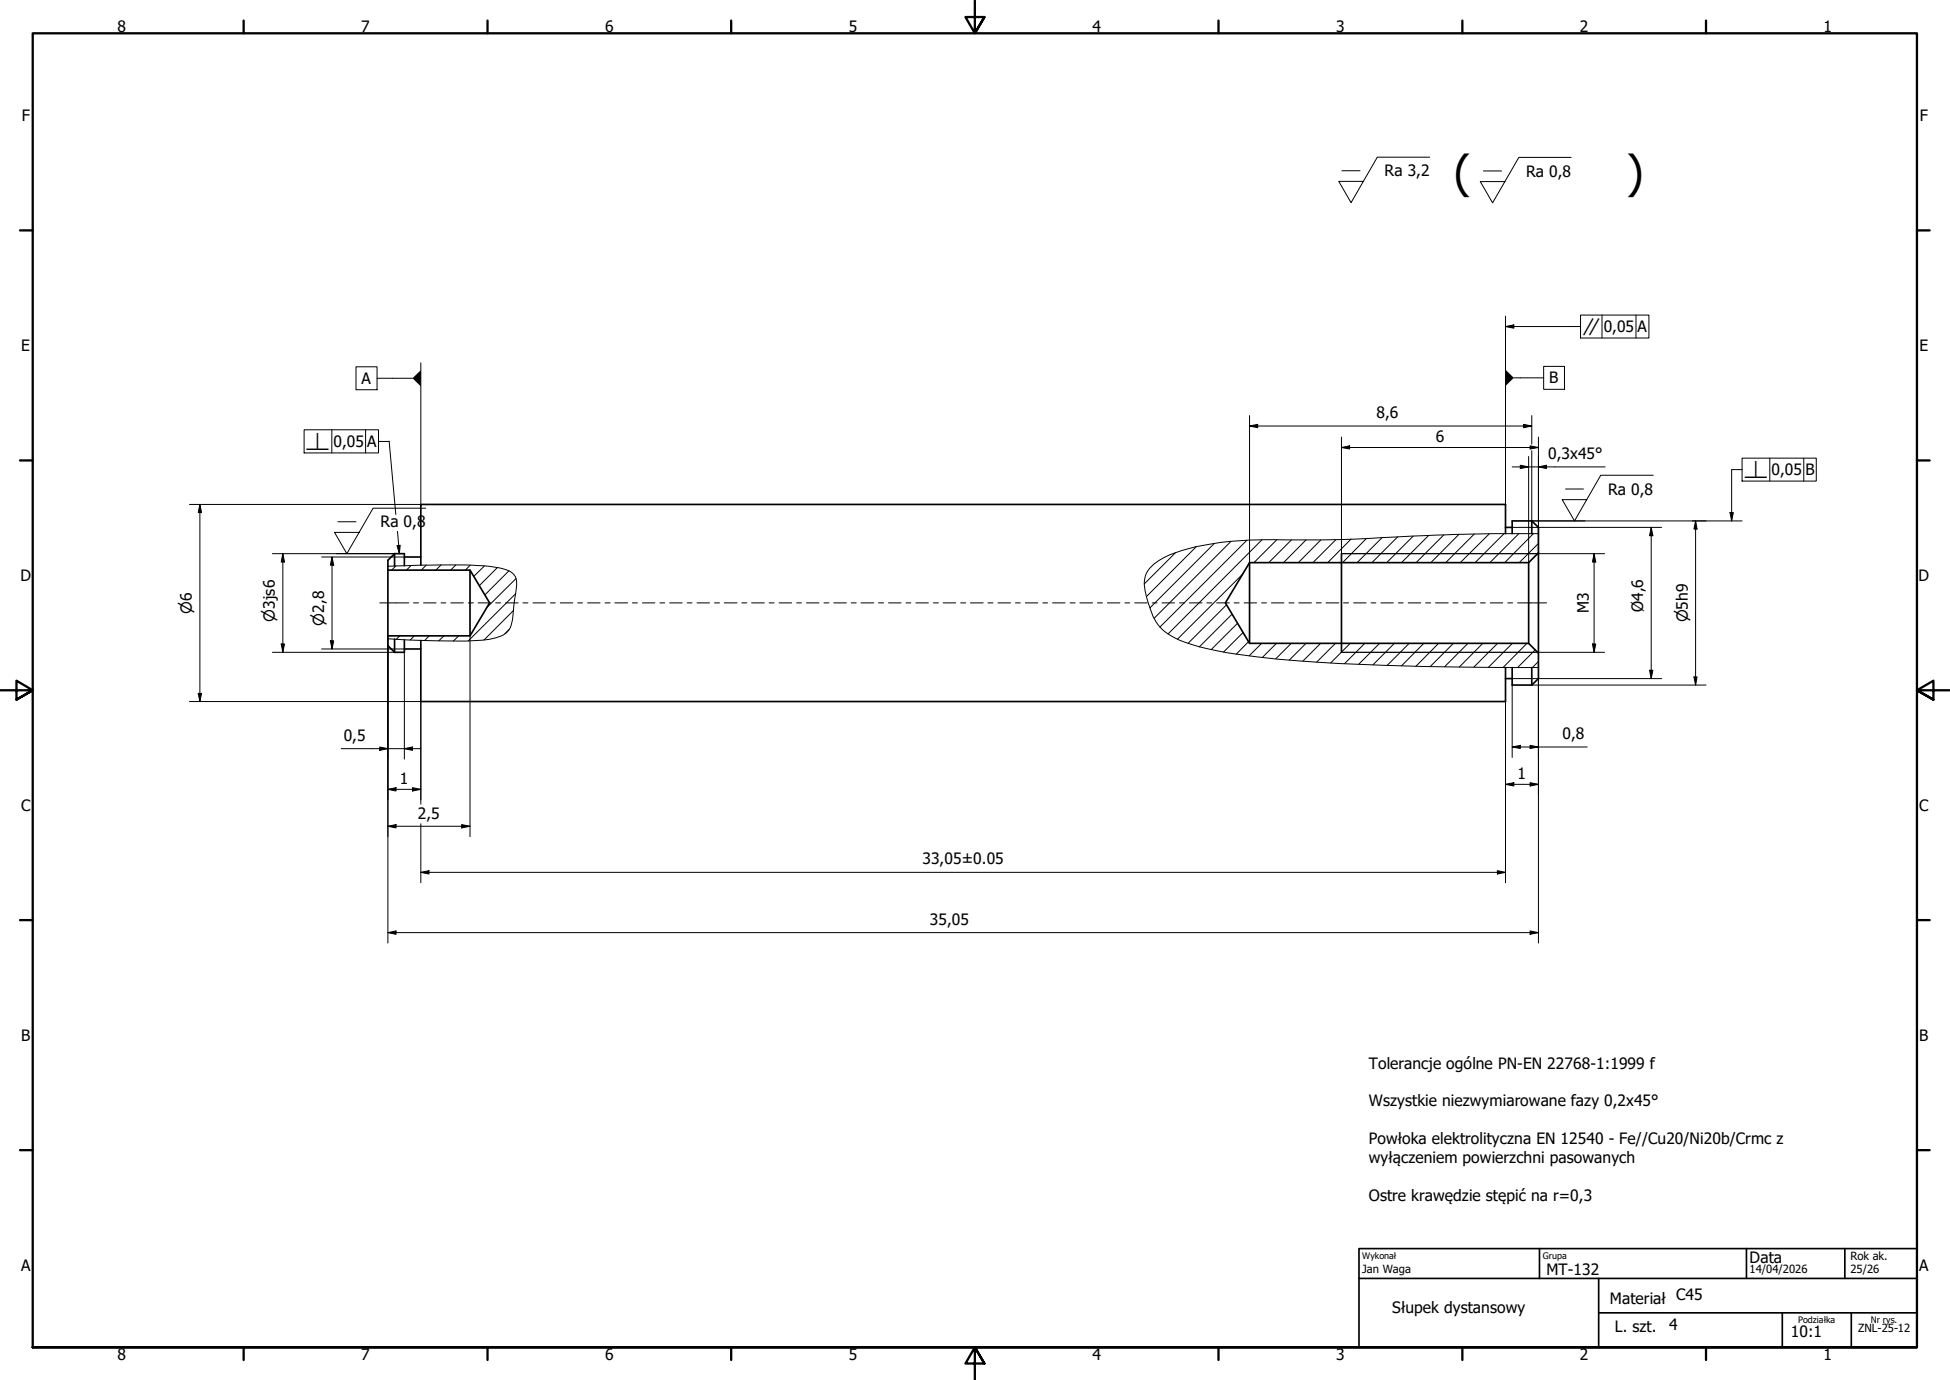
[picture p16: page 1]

Tolerancje ogólne PN-EN 22768-1:1999 f

Wszystkie niezwymiarowane fazy 0,2x45°

Powłoka elektrolityczna EN 12540 - Fe//Cu20/Ni20b/Crmc z
wyłączeniem powierzchni pasowanych

Ostre krawędzie stępić na r=0,3

Wykonał Jan Waga | Grupa MT-132 | Data 14/04/2026 | Rok ak. 25/26

Słupek dystansowy | C45 Materiał

4 L. szt. | Podziałka 10:1 | ZNL-25-12 Nr rys.

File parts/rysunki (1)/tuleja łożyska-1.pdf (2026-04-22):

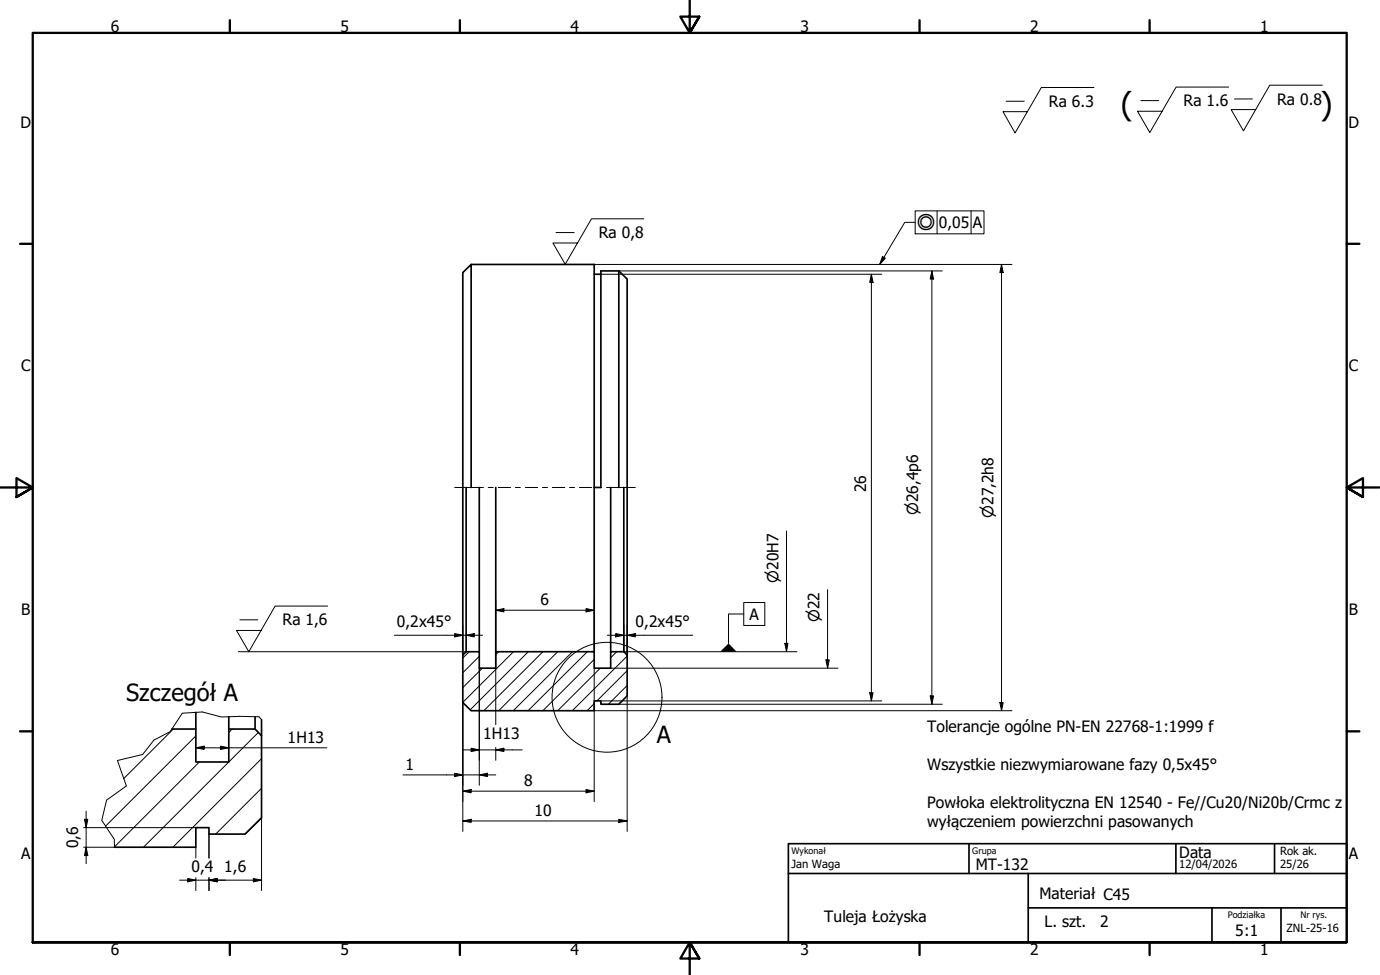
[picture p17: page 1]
Szczegół A

Tolerancje ogólne PN-EN 22768-1:1999 f

Wszystkie niezwymiarowane fazy 0,5x45°

Powłoka elektrolityczna EN 12540 - Fe//Cu20/Ni20b/Crmc z
wyłączeniem powierzchni pasowanych

Wykonał Jan Waga | Grupa MT-132 | Data 12/04/2026 | Rok ak. 25/26

Tuleja Łożyska | Materiał C45

L. szt. 2 | Podziałka 5:1 | Nr rys. ZNL-25-16

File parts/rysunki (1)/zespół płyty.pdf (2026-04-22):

roznitować, wyrównać

Nr. | L. szt. | Nazwa | Materiał | Rys.
1 | 1 | płyta silnika | C45 | ZNL-25-08
2 | 4 | słupek | C45 | ZNL-25-12
3 | 1 | tuleja łożyska | C45 | ZNL-25-08

Wykonał Jan Waga | Grupa MT-132 | Data 19/04/2026 | Rok ak. 25/26

Zespół płyty | L 1 | Podziałka 5:1 | Nr rys. . szt. ZNL-25-19
